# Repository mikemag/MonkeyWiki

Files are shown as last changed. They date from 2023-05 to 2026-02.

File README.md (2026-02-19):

# MonkeyWiki

This is the source for the content at https://www.happymonkeysnowboards.com/MonkeyWiki.

This was all converted from the Wiki version of MonkeyWiki in May, 2023. Hopefully I got everything right!

# Donate

You can help offset the server costs for running [MonkeyWiki](https://www.happymonkeysnowboards.com/MonkeyWiki) with a small donation. 



# Requirements

* hugo v0.154.2+extended or higher
* [Hugo Book Theme](https://github.com/alex-shpak/hugo-book) @ 81a841c92d62f2ed8d9134b0b18623b8b2471661

# License

Code is licensed under the MIT license except as otherwise noted.
See [LICENSE](https://github.com/mikemag/MonkeyWiki/blob/main/LICENSE) for details.

Documents and images are copyright by [Michael Magruder](https://github.com/mikemag) and licensed under a
[Creative Commons Attribution-ShareAlike 4.0 International License](http://creativecommons.org/licenses/by-sa/4.0/).

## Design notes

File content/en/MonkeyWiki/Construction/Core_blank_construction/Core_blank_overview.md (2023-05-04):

---
dateFromWiki: "2019-02-02T07:45:15Z"
title: "Core blank overview"
aliases:
- /MonkeyWiki/Core_blank_overview
- /MonkeyWiki/Core_blank_overview/en
weight: 1
---
Snowboard cores are typically composed of vertically laminated strips of wood about 2cm wide. The core is machined from a “core blank,” which is usually rectangular, longer, wider, and thicker than the final core.

Making a core blank is a fairly classic woodworking process, and you should approach it as such. If you’re new to woodworking I have collected a lot of [Woodworking Resources]({{< ref "MonkeyWiki/Resources/Woodworking_Resources.md" >}}) to help you get started. 

## Overview 
For snowboard cores, I build blanks that are about 13.5” wide, 0.400" thick, and about 6-7’ long. Each blank has 18 strips of poplar running lengthwise. The blank is held together with Polyurethane glue.

The process starts with poplar boards which are a bit over 7’ long, 2.5” wide, and approximately 3/4" thick. Nine of these boards are glued into a stack 7’ long, 2.5” wide, and 6.75” thick. The stack is sliced into 4 planks each 7’ long, 6.75” wide, and about 1/2" thick. Two slices are then joined together to make a blank 7’ long, 13.5” wide, and 0.400-0.500" thick. 

So, nine **boards** &rArr; one **stack** &rArr; four **slices** &rArr; two **blanks**. I will use the terms board, stack, slice, and blank to refer to the various stages of construction below.

I usually try to make about ten blanks at a time, so I start with at least 45 poplar boards. (I usually buy closer to 50 because sometimes what looks like a good board at the store doesn’t look so good in your shop!) I find that making many blanks at once is easier than making one at a time. Core blanks are very stable and can sit on the shelf for a very long time without warping or cracking.

## See Also 
- [Wood selection, drying, and prep]({{< ref "MonkeyWiki/Materials/Wood_selection__drying__and_prep.md" >}})
- [Building a stack]({{< ref "MonkeyWiki/Construction/Core_blank_construction/Building_a_stack.md" >}})
- [Slicing a stack]({{< ref "MonkeyWiki/Construction/Core_blank_construction/Slicing_a_stack.md" >}})
- [Joining the halves of a core blank]({{< ref "MonkeyWiki/Construction/Core_blank_construction/Joining_the_halves_of_a_core_blank.md" >}})

## To-do 
- Drawing of the progression from boards to blanks. Used to have one on the original HMS site… probably re-do it to make it look a bit less ghetto.
- Pics of each stage, just one per stage.

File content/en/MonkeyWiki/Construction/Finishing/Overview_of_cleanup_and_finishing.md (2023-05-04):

---
dateFromWiki: "2019-02-03T02:29:52Z"
title: "Overview of cleanup and finishing"
gallery: true
aliases:
- /MonkeyWiki/Overview_of_cleanup_and_finishing
- /MonkeyWiki/Overview_of_cleanup_and_finishing/en
weight: 1
---
{{< img src="images/Board_Trimmed.JPG" caption="_Snowboard with edges trimmed and cleaned up._" >}}After the board comes out of the press we still have a lot of cleanup work to be done before it really starts looking like a snowboard.

## Trimming the flash 
 
The first step is trim off the “flash”, which is the leftover material beyond the edge of the snowboard. This consists of extra fiberglass, cured epoxy, rubber, top sheet, nose/tail spacers, and sidewall material. I start by using a bandsaw to remove the flash from along the effective edge of the board. This is easily done by allowing the bandsaw blade to press against the metal snowboard edge. It is also possible to remove the flash from the nose and tail using the bandsaw, but I chose to cut these portions away using a jigsaw with an abrasive bit. It’s much easier (for me) to hold the board steady on a workbench and guide the jigsaw carefully around the tighter nose and tail radius than it is to swing the entire board around the bandsaw blade. 

@TODO: get the info on the blade I use.

{{< gallery  caption="Flash Cleanup" >}}
{{< gallery-item src="images/FlashCleanup1.JPG" caption="Remains of the nose and tail flash." >}}
{{< gallery-item src="images/FlashCleanup2.JPG" caption="Remains of the flash from along the edge of a snowboard." >}}
{{< /gallery >}}

## Cleaning the edges 
 
Now the laminate is starting to look more like a snowboard, but the edges are very rough. Both tools leave a rough edge, and in places there will still be a thin layer of excess material, usually PTEX sidewall or nose/tail spacer. A 4” angle grinder with a 60 grit flap sanding disc is used along the entire perimeter of the board. Excess material is carefully ground away, and the full edge is exposed. I then switch to a 120 grit flap sanding disc and cleanup the nose and tail portions of the board completely. This will be the final treatment these parts of the board receive. This is a pretty delicate process. You can do a lot of damage to the edge of the board with an angle grinder and a 60 or 120 grit disc in an amazingly short period of time!
 
It is critical that you not overheat the edges while grinding with the angle grinder. I constantly move to another area even before the portion I’m working on is done. I spray liberally with clean water as I do, and check the temperature of the edge with my hand. If you can’t hold your hand on the edge, then it’s too hot.

{{< gallery  caption="Edge cleanup" >}}
{{< gallery-item src="images/EdgeCleanup1.JPG" caption="The table where I cleanup the board. Snowboard vises are used to hold the board up on edge for grinding." >}}
{{< gallery-item src="images/EdgeCleanup2.JPG" caption="Laminate trimmer and angle grinder with various flap sanding discs." >}}
{{< /gallery >}}

## Base grind 
 
{{< img src="images/BaseGrinder.JPG" caption="_Base grinder_" >}}Next, the board gets its first base grind. I start with a coarse 80 grit belt to quickly remove the excess epoxy and a thin layer of base material, then switch to a 120 grit belt for the final grind. While the 80 grit belt is still in place, I cleanup the effective edge holding the board perpendicular to the base grinder. This ensures that the full length of the edge is smooth and even the length of the board.

## Beveling the sidewalls 
 
Next, the board is returned to the work bench where the sidewall bevel is applied. A laminate trimmer with a tilt base is used to run a flush trim router bit along the length of the effective edge. This gives the sidewall a perfect 10 degree bevel, and is the last bit of cleanup needed on the sidewalls. If you don’t have a laminate trimmer with a tilt base you can build a wedge out of wood and attach it to the base of your router to form the correct angle.
 
The key here is to move slowly and ensure that the base of the trimmer remains flat against the base of the board. Ease into and out of the cut at each end, and blend any sharp transition that might be left with a sanding block.

{{< gallery  caption="Sidewall cleanup" >}}
{{< gallery-item src="images/Trimmer1.jpg" caption="Laminate trimmer with a tilt base." >}}
{{< gallery-item src="images/Trimmer2.jpg" caption="Straight cutter with bearing on top." >}}
{{< gallery-item src="images/Trimmer3.jpg" caption="Example of how to apply the trimmer to cleaning up sidewalls. The edge should be completely exposed and smooth. The bearing rests on the edge, and the cutter starts about a half millimeter past the edge. The board is upside down and the trimmer rests on the base." >}}
{{< /gallery >}}

## Exposing the inserts 
 
Finally, the inserts are drilled out. I locate the inserts by using two small magnets that will stick to two 3/16” steel ball bearings that I placed in the guide inserts during preparation for layup. The guide inserts are centered along the length of the board, and 4cm from the first set of inserts. Using a guide I can quickly mark where the inserts are below the surface of the board, then drill them out in two steps. The first step is to use a 1/8” drill bit to open up the inserts, then a 45 degree counter sink to expose the full inserts and leave a nice bevel. The counter sink will self-center in the insert. Keep the drill perpendicular to the board to ensure an even, round hole. The threads are cleaned up with a M6 tap, and checked by running a binding screw down into each insert by hand. If the screw doesn’t feed easily all the way to the bottom, the tap is used again until it does.
 
Use a small pair of tweezers to remove bits of the mylar insert cap that get pushed down during drilling and counter sinking. Clear the inserts with compressed air before tapping and before running the screw down.
 
Go easy with the M6 tap. You don’t want to cross thread it and destroy the threads in an insert. You also don’t want to run it too far down and push out the base of the insert, which would leave a dimple on the bottom of the board. Most taps come with a point at the end. It’s best to grind this down to a flat bottom, as shown in the pictures below.

{{< gallery  caption="Insert cleanup" >}}
{{< gallery-item src="images/CleanupInserts1.JPG" caption="Insert finding guide, aligned with magnets." >}}
{{< gallery-item src="images/CleanupInserts2.JPG" caption="Insert finding guide, aligned with magnets." >}}
{{< gallery-item src="images/CleanupInserts3.JPG" caption="Insert finding guide, aligned with magnets." >}}
{{< gallery-item src="images/CleanupInserts4.JPG" caption="Inserts drilled with a small drill bit." >}}
{{< gallery-item src="images/CleanupInserts5.JPG" caption="Inserts exposed with the counter sink." >}}
{{< gallery-item src="images/CleanupInserts6.JPG" caption="Here you can see bits of epoxy and glass forced down into the inserts after drilling with the counter sink." >}}
{{< gallery-item src="images/CleanupInserts7.JPG" caption="Cleaning up the threads of the inserts with a M6 tap." >}}
{{< gallery-item src="images/CleanupInserts8.JPG" caption="Testing the insert threads with a binding screw." >}}
{{< /gallery >}}

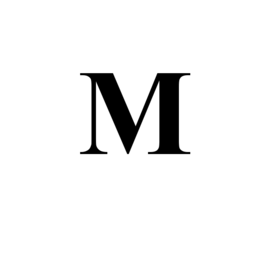
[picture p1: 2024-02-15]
static/mstile-150x150.png

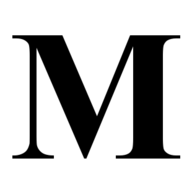
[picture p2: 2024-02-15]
static/android-chrome-192x192.png

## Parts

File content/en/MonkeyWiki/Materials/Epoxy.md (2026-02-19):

---
title: "Epoxy"
gallery: true
aliases:
  - /MonkeyWiki/Epoxy
  - /MonkeyWiki/Epoxy/en
---

{{< img src="images/Epoxy1.JPG" >}}
{{< img src="images/Epoxy2.JPG" >}}
I used an epoxy system specifically designed for ski and snowboard applications
by QCM Industrial, who used to be a local company. The epoxy is designed to be flexed and resist impact at
extremely low temperatures. The epoxy resin (EMV-0049) and hardener (ECA-032) are mixed by weight. It's measured out and
weighed to the gram, then mixed thoroughly. The boards are pressed with carefully controlled heating, on the top and
bottom of the board, to cure the epoxy properly so it will develop its full properties. The manufacturer recommends a
heated cure of 180F for this particular epoxy system.

### QCM no longer available

Note: this QCM epoxy is no longer available. They sold their formula to Forrest Paint who produced it for a few
years but they also stopped. I don't have a recommendation for different epoxy since I don't have any direct
experience with others for snowboard building. 

For posterity's sake, here are the data sheets on EMV-0043 and ECA-032. I don't have a copy of the EMV-0049 datasheet, 
but this is close enough. I switched to EMV-0043 at some point, I don't recall when.

- [EMV-0043 Data Sheet](/files/EMV-0043.pdf)
- [ECA-032 Data Sheet](/files/ECA-032.pdf)

## Quality Control

Whenever you get a new batch of epoxy you should label the cans and always use them in sets. Mix a 100g test sample,
cure it properly, and do a basic stress test on it (i.e., break it). Ensure it behaves as you expect, and as it has for
you in the past. One time I got a can of resin that was incorrect, and the 100g sample showed the problem immediately. I
took the cans and the sample back to the manufacturer, and they apologized and replace it right away.

If you’re selling your boards or skis, I highly recommend recording which batches of epoxy you use in each build. Save
the tests so you can refer back to them if someone reports a problem.

## Measurement

Every epoxy system is different: some are measured and mixed by **volume**, and some are measured by **weight**. It is
important you know which way you should measure for your epoxy. Mixing by volume with epoxy that needs to be mixed by
weight will result in either too much hardener (and it will kick too fast) or too little, in which case the epoxy will
not cure properly.

## Mixing

I use a “two-cup” mixing method. I use two cups which are individually large enough to hold the entire volume of mixed
epoxy. I measure out the hardener into Cup A and the resin into Cup B. I pour the hardener from Cup A to Cup B, and mix
thoroughly in Cup B. I then pour Cup B into Cup A, being careful to scrape the bottom and sides of Cup B to make sure I
get any un-mixed resin out. I then continue to mix in Cup A. This ensures that no resin is left on the bottom of Cup B.

A good trick you can use to help you learn if you’re mixing well or not is to add a very small amount of pigment to your
hardener before you start mixing. Pickup a small bottle of epoxy pigment and put just a smidge (dab the tip of a tongue
depressor in it) into the hardener and mix will. Now when you mix the hardener with the resin you will see easily any
unmixed resin. This small amount of pigment will not appreciably color your final mix of epoxy, and will be unnoticeable
in your final board.

## Safety

There are two safety aspects to be concerned about: fire, and long-term sensitivity.

### Fire

Epoxy cures via an [exothermic reaction](http://en.wikipedia.org/wiki/Exothermic_reaction). That means it generates heat
while it cures, and as it gets warmer it generates more heat. Given enough epoxy and heat this reaction can “run away”
and generate an amazing amount of heat, enough to ignite the epoxy or whatever it is near. Needless to say, that’s bad.
Even if it doesn’t ignite it can smolder and generate a toxic smoke that you should avoid.

'*Leftover epoxy should simply *never* be left in a cup when you are done with it.*' Pour it out onto a plastic picnic
plate or something equally disposable and let it cure slowly in a thin film. Never leave a cup with even an inch of
epoxy in the bottom sit to cure on its own, or toss such a cup in the trash, etc.

### Sensitivity

You should keep epoxy off your skin, and avoid inhaling epoxy dust as you process your board or skis after pressing.
Some people can develop a sensitivity to the chemicals in epoxy with repeated exposure over a long period of time. This
can cause skin rashes or breathing problems when exposed to a minimal amount of epoxy, and essentially leave you in the
position of not being able to work with it again.

Rubber gloves, long-sleeve work shirts, and simple dust masks are your friends here. Use them every time.

- [Health risks of epoxy at Wikipedia](http://en.wikipedia.org/wiki/Epoxy#Health_risks)
- [Epoxy School article on sensitization](http://www.epoxyschool.com/blog/?p=397)

## Interview with an epoxy chemist

[SkiBuilders](http://skibuilders.com) did a [Q&A with Roy Wheeldon](http://www.skibuilders.com/articles/epoxy.shtml)
back in 2007. He was the head chemist at QCM, Inc., the original makers of the epoxy that I and many others use for skis
and snowboards. It’s an excellent read and I highly recommend it. Roy was a nice guy and always helpful to small
builders like myself. I had the pleasure of talking with him about what I was doing many times. Sadly, Roy passed away a
few years ago.

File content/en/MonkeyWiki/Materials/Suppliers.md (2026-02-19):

---
title: "Suppliers"
aliases:
- /MonkeyWiki/Suppliers
- /MonkeyWiki/Suppliers/en
weight: 1
---

## Home Builders 
For home builders who are just making a few boards casually, I highly recommend starting with [Blank Slate Skis](http://www.blankslateskis.com/), which is run by Kelvin Wu of [Maiden Skis](https://maidenskis.com/). Kelvin is one of the original founders of the [SkiBuilders.com Forum](http://www.skibuilders.com/phpBB2/) and an all-around good guy. He supplies small builders with the same high quality materials he uses on his skis.

Next, take a look at [snowboardmaterials.com](https://snowboardmaterials.com/), which has been around longer than any other small supplier and has everything you need to get started. 

## Small Professional Builders 

For small professional builders, to get cost down you need to buy in quantity. Here are the sources I used at Happy Monkey throughout the years. Hopefully these sources remain available, as it is actually rare to find big businesses willing to sell in small quantities. I'll try to update this over time as I hear that things change, but I build about a board per year now so I don't buy supplies that often anymore. If you find a supplier that's out of date, or have a suggestion of one to add, please let me know!

This list focuses on North American suppliers, because that's where I am.

Be prepared to order in real quantity, and be prepared to be at the bottom of the priority list. Sourcing material in bulk, and ensuring you have it when you need it will be a test of your long-term logistical skills… leave lots of time to replenish.

- [CDW Edge](https://www.waelzholz.com/en/company/international/usa.html) - now owned by [Waelzholz](https://www.waelzholz-skikanten.de/en.html), but apparently still making and selling edges in Cleveland, OH. 
- [Crown Plastics](https://crownplastics.com/) - DuraSurf base material, nose & tail fill, PTEX sidewalls, clear top sheets. Crown is a large supplier, but has been solid when it comes to supplying smaller builders.
- [Composites One](https://www.compositesone.com/) - fibers, and where I got all of my Vectorply fiberglass. 
- [Fiberlay](http://www.fiberlay.com/) - small-quantity fibers, a good place to get bits of carbon and Kevlar.
- [Custom Components Group, Inc.](http://www.customcomponentsgroup.com) - all manner of inserts. This is where I got all of mine.
- [Miller Studio](http://www.millerstudio.net/) - printed top sheets. Vince Miller is awesome to work with. He did all of my printed top sheets before I switched to wood veneer. He'll help you figure out what you need and you'll end up with great graphics. Singles or bulk. He also sells bulk top sheet and base material.
- **UPDATE: Forrest has stopped making QCM epoxy.** 
  - [FORREST Technical Coatings](http://forrestpaint.com/) - this is who bought QCM's epoxy formulas when they stopped making epoxy. Call them up, tell them you're looking for the ski and snowboard specific epoxy QCM used to make and they'll know what you're talking about. I used to use QCM product numbers ECA-032 and EMV-049. Forrest still makes the ECA-032 as their [FORREST Medium Cure Hardner](http://forresttechblog.com/sportboard-builders-qcm/forrest-medium-cure-hardner/), and they have EMV-043, which I use now, as their [FORREST Epoxy Resin 218S000](http://forresttechblog.com/sportboard-builders-qcm/forrest-epoxy-resin-218s000/).
- [Michaels Enterprises, Inc.](https://www.michaelsenterprises.com) - heat blankets for your press. I got mine here, and they've held up for 15 years at this point.
- [McMaster-Carr](https://www.mcmaster.com/) - any part for any machine, tools, shop supplies, etc. I love this place. They have 3D models for all of their machine parts, which you can import directly into your favorite CAD system. Use this when designing new equipment.
- [Veneer Supplies](https://www.veneersupplies.com/) - great online supplier of wood veneer. Massive selection, excellent shipping. I've gotten a lot from here.
- CAMAX Tool Company, Inc. - inserts, famous for their magnetic capped inserts. I've never used them, but lots of people have. They don't seem to have a website, but they're in Ft. Morgan, Colorado, and you can google up a phone number.
- [Airtech](https://www.airtechonline.com/) - all things vacuum bagging, including tools.

Seattle-area suppliers:

- [Edensaw](http://www.edensaw.com/) - wood veneer mecca. You can go to their warehouse in Tacoma and look at the veneer before you buy it. They require you to take whole bundles, and they may not let you take a single bundle from the middle of a log. They often have broken bundles you can buy a few sheets from.
- [Compton Lumber](https://www.comptonlbr.com) - excellent source for core wood, like Poplar, Ash, etc. Good selection and prices. I've gotten all of my core wood from them for over a decade.
- [Alaskan Copper](http://www.alascop.com/) - great source of metal. I get my mold skins from them.
- [Eastside Saw & Sales](http://www.eastsidesaw.com/) - router bits, bandsaw blades, sharpening, etc.
- [Woodcraft Seattle](https://www.woodcraft.com/stores/seattle) - standard woodworking store. Rockler is good too, but you've gotta have your go-to woodworking store and this is mine.

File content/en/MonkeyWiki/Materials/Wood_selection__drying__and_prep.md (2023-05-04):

---
dateFromWiki: "2019-02-12T01:41:23Z"
title: "Wood selection, drying, and prep"
gallery: true
aliases:
- /MonkeyWiki/Wood_selection,_drying,_and_prep
- /MonkeyWiki/Wood_selection,_drying,_and_prep/en
---
{{< img src="images/Core_Wood.JPG" caption="_Poplar from Compton Lumber in Seattle._" >}}You can make a core blank out of pretty much any type of wood. The only wood I use in my blanks is poplar; I add a bit of ash along the edge of the core later when [Ash edge stringer and sidewalls]({{< ref "MonkeyWiki/Construction/Core_construction/Ash_edge_stringer_and_sidewalls.md" >}}). Many people use combinations of various types of wood throughout the core, in different patterns. Almost anything will work, so be creative.

{{< img src="images/Core_Wood_Clear.JPG" caption="_Clear poplar._" >}}No matter which type of wood you use, selecting quality boards is critical. You want clear boards with even grain, no knots, and preferably as straight as possible. Ideally all of the boards should be a bit longer than the final core blank length.

The best place to source your core wood is a dedicated lumber yard that sells rough cut wood. It is rarely cost-effective to get your wood at a big-box store like Home Depot or Lowes, even if they have the wood you want. In the Seattle area there are many excellent options. I always get my core wood from [Compton Lumber](http://www.comptonlbr.com/). They have an excellent selection of rough poplar as well as poplar already machined to the size I need. I also get my ash from them, always rough cut. You can spend the time at a place like Compton to pick through their stacks of wood and find just the boards you’re looking for. 

Other good choices in the Seattle area are [Crosscut Hardwoods](http://www.crosscuthardwoods.com/), and if you’re closer to the Olympic peninsula [Edensaw](http://edensaw.com/).

Purchasing wood from a real hardwood supplier is often confusing. There are a lot of odd terms that you may not initially be familiar with. [The Language of the Lumberyard](https://www.finewoodworking.com/2011/07/28/the-language-of-the-lumberyard) at Fine Woodworking is a good introduction to the topic, as is the video blog entry [A Lumbering Feeling](http://thewoodwhisperer.com/episode-4-a-lumbering-feeling/) from The Wood Whisperer.

{{< img src="images/Core_Wood_Blemish1.JPG" caption="_Knots at the ends can be okay._" >}}You want FAS (firsts and seconds), as clear as possible, and straight with minimal twisting or bowing. If you want it already prepared so you don’t need to do much work to the wood get S4S (surfaced on four sides). Note that if a board has a knot or other blemish near the end it may be alright. Often blanks come out much longer than they need to be and a knot near the end would not be included in the final core when cut.

## Preparing the boards 
We need poplar boards which are at least 7’ long, 2.5” wide, and about 0.75” thick, and we’ll need nine per stack. Happily, Compton Lumber sells poplar already machined perfectly to 2.5” wide and 0.75” thick in lengths ranging from 6’-8’. If I find a bunch of 6’ board I’ll tend to make some blanks for shorter boards… these blanks will tend to end up about 175-180cm long, which can yield cores of 173-178cm.

If you can’t find your wood already cut as you need then you can start from rough stock. This is the way I used to start before I got lucky with Compton. There is an excellent article from Fine Woodworking on turning rough cut lumber into useful boards here: @TODO. Following this process requires a table saw, a jointer, and a planer, all of which you need anyway for steps later in the process. It takes some extra time to do this, in particular some extra acclimation time for the wood (see below), but it’s a bit cheaper to start with rough wood that it is to buy it pre-machined, and you can customize the thickness of the strips in your core. 

## Acclimating the wood to your shop 
No matter how you get your boards you need to first let them adjust to the climate in your shop. Wood moves with moisture changes, and the moisture content of your shop if often quite different than the place you bought it from. Stack the wood on a flat bench with “stickers” in between; small pieces of wood used to separate the boards and let air flow around them. Place some heavier boards on the top of the stack to help ensure that the wood remains as flat as possible, and make sure that the stickers line up one on top of the other. Let the wood rest in your shop for at least a few days if you have narrow boards, and longer for thicker/wider boards. The wood will change shape slightly then stabilize. It’s better for it to change shape before you try to build something with it than during or afterwards. 

{{< gallery  caption="Drying core wood" >}}
{{< gallery-item src="images/Core_Wood_Drying1.JPG" caption="2.5\" x 0.75\" x 6-8' poplar stickered and drying before use as core wood." >}}
{{< gallery-item src="images/Core_Wood_Drying2.JPG" caption="2.5\" x 0.75\" x 6-8' poplar stickered and drying before use as core wood." >}}
{{< gallery-item src="images/Core_Wood_Drying3.JPG" caption="2.5\" x 0.75\" x 6-8' poplar stickered and drying before use as core wood." >}}
{{< /gallery >}}

## See Also 
- [Core blank overview]({{< ref "MonkeyWiki/Construction/Core_blank_construction/Core_blank_overview.md" >}})
- [Building a stack]({{< ref "MonkeyWiki/Construction/Core_blank_construction/Building_a_stack.md" >}})
- [Slicing a stack]({{< ref "MonkeyWiki/Construction/Core_blank_construction/Slicing_a_stack.md" >}})
- [Joining the halves of a core blank]({{< ref "MonkeyWiki/Construction/Core_blank_construction/Joining_the_halves_of_a_core_blank.md" >}})

## To-do 
- Article link on taking wood from rough to S4S.

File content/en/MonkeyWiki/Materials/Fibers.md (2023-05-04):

---
dateFromWiki: "2019-03-23T19:00:30Z"
title: "Fibers"
gallery: true
aliases:
- /MonkeyWiki/Fibers
- /MonkeyWiki/Fibers/en
---

## Glass 
{{< img src="images/Fibers1.JPG" >}}The primary reinforcement I use in my boards is 
[Vectorply](http://www.vectorply.com/) [E-TLX 2200](http://vectorply.com/wp-content/uploads/2015/06/E-TLX-22001.pdf), 
which is a stitched triaxial E-Glass. 54% of the fibers run in the longitudinal direction (0 degrees) while the other 
46% of the fibers are evenly divided between the 45 and -45 degree directions. The fibers are stitched together in three 
layers, rather than being woven like tradition fiberglass, which is what most of us are familiar with. 
[E-TLX-1900](http://vectorply.com/wp-content/uploads/2015/06/E-TLX-19001.pdf) is a nice, slightly lighter alternative 
which keeps the same volume of fibers in the +/-45 degree directions.

## Stitched vs. Woven Fabrics  
I greatly prefer non-woven fabrics for snowboard and ski applications. Weaving causes stress points everyplace a bundle 
of fibers crosses over or under another bundle. The constant flexing of a snowboard causes a rapid breakdown of the resin 
around these stress points, leaving the fibers unsupported and thus prone to breaking. Boards built with woven fabrics 
lose their stiffness far more quickly than we find acceptable. Stitched fabrics allow the fibers of each layer to lay 
flat on top of each other yielding a stronger laminate over time. Further, stitched fabrics trap less resin than woven, 
resulting in a lighter laminate.

Vectorply has a good page on the differences between woven and stitched fabrics for these kinds of applications. Here's a good summary from their page:

> The crimping of yarns, inherent in weaving, causes stress points in the laminate and a subsequent knockdown in strength 
> and stiffness. Pound for pound non-crimp reinforcements are 30% stronger than woven fabrics. Secondly, the coarse surface 
> created by the weaving of fibers translates into poor shear properties because of less fiber-to-fiber contact. Third, the 
> interstices created by the weave allow resin to pool amongst the rovings contributing to lower properties, adding unwanted weight and cost.

-- *Vectorply. (n.d.). Stitch-Bonded Reinforcements. Retrieved from http://vectorply.com/stitch-bonded-reinforcements/ on 2019/02/08.*

## Carbon and Kevlar  
{{< img src="images/Fibers9.JPG" >}}In addition to the fiberglass, I use Kevlar and carbon fiber in various places. 
Every board gets a very light weave of Kevlar backing the inserts. And, yes, having just explained why woven fabrics 
are bad in snowboards, this small application of such a light Kevlar weave is alright in this area as it receives so 
little flex. A patch of Kevlar which the inserts are pushed through provides stronger insert retention, and greatly 
reduces “binding suck”: that phenomena where the base underneath the bindings tends to suck in to the core when the 
bindings are tightened.
 
Unidirectional Kevlar or carbon is used on some boards to provide extra stiffness and pop depending on the application. 
An especially large board might be reinforced with Kevlar strips along the base to help provide stiffness while keeping 
the core thinner, and thus reducing weight. Kevlar or carbon may be used in just the nose or tail section, or spread 
between the bindings and the nose or tail in order to give more torsional rigidity. I use 1” wide unidirectional Kevlar 
and carbon fiber, and in some applications many very thin strips of carbon roving.

Note: Unused KEVLAR® should be stored away from UV light. It will degrade in UV light.

{{< gallery  caption="Various fibers and reinforcements" >}}
{{< gallery-item src="images/Fibers2.JPG" caption="Placement of 1” unidirectional Kevlar along the base of a 200cm custom board." >}}
{{< gallery-item src="images/Fibers3.JPG" caption="Light Kevlar weave to back the inserts. Slits are cut to allow the barrel of the inserts to pass through and still keep the Kevlar flat and even behind the inserts." >}}
{{< gallery-item src="images/Fibers4.JPG" caption="Close up of 1” unidirectional Kevlar." >}}
{{< gallery-item src="images/Fibers5.JPG" caption="Placement of 1” unidirectional Kevlar along the base of a 200cm custom board." >}}
{{< gallery-item src="images/Fibers6.JPG" caption="Unidirectional carbon fiber, 1” and 12”." >}}
{{< gallery-item src="images/Fibers7.JPG" caption="Detail of unidirectional carbon fibers." >}}
{{< gallery-item src="images/Fibers8.JPG" caption="Carbon fiber roving." >}}
{{< /gallery >}}

## Fibers I've Used 
- [Vectorply](http://www.vectorply.com/) [E-TLX 2200](http://vectorply.com/wp-content/uploads/2015/06/E-TLX-22001.pdf)
- [Vectorply](http://www.vectorply.com/) [E-TLX-1900](http://vectorply.com/wp-content/uploads/2015/06/E-TLX-19001.pdf)
- Kevlar, biax, woven, 1.70 oz./yd.² (58 g/m²) Warp 34 Kevlar 49 195 Denier x Fill 34 Kevlar 49 195 Denier, Plain Weave, 3.0 mils (.08 mm) Thickness.
- Kevlar, unidirectional, heat set binder, 0.010" x 1", 6.8 oz./yd.².
- Carbon Fiber, unidirectional, heat set binder, 0.008" x 1", 5.3 oz./yd.².
- Carbon Fiber, unidirectional, 0.007" x 2.25", [Hexcel HexForce GA045](https://www.hexcel.com/user_area/content_media/raw/DSF_ga045.pdf), 4.4 oz./yd.², 6k.
- Carbon Fiber, unidirectional, 0.010" x 12", Hexcel GA060, 6.7 oz./yd.² (227 g/m²), Warp 7 12K Carbon x Fill 4 Proprietary Heatset, Plain Weave, 10.1 mils (.26 mm) Thickness.  
- Carbon Fiber, raw tow, [roll from EBay long ago](https://www.ebay.com/itm/AMOCO-CYTEC-THORNEL-P-100-2K-HIGH-STIFFNESS-CARBON-GRAPHITE-FIBER-TOW-THREAD/263531049599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), Aomco Performance Products, Inc., P100-2K, grade 304-NT, 1.02lbs, 4800ft, 0.003-0.004" x ~3mm. 110 Msi, 348 ksi, 10 um filament diameter, 2880 denier / 3200 dtex (0.32 g/m). 

## Safety  

Glass, carbon, and Kevlar fibers are very small and easily penetrate your skin. They also float in the air and are easily inhaled, 
where they settle in your lungs. Wear gloves when handling the fibers. Wear a very high quality dust mask and goggles when cutting 
any of these materials, either raw or in a laminate. This is especially important when trimming the flash from a ski or snowboard, 
and when sanding the sides of the boards, as this generates a great deal of fiber-rich dust.

## Terms 
- [Tow](https://en.wikipedia.org/wiki/Tow) - the raw fiber thread used to weave fabrics, i.e., an untwisted bundle of continuous filaments. A 2K tow is 2000 threads.   
- [Denier](https://en.wikipedia.org/wiki/Units_of_textile_measurement#Denier) - fiber thickness of individual threads.

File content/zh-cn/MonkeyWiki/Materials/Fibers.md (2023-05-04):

---
dateFromWiki: "2020-04-28T09:25:31Z"
title: "纤维织物"
gallery: true
aliases:
- /MonkeyWiki/Fibers/zh-cn
translatedDate: "2020-04-28T09:25:31Z"
translator: "X z"
translatorPage: "/zh-cn/MonkeyWiki/X_z"
---

==玻璃纤维==

{{< img src="images/Fibers1.JPG" >}}我在我的板上使用的主要强化是[Vectorply](http://www.vectorply.com/) [E-TLX 2200](http://vectorply.com/wp-content/uploads/2015/06/E-TLX-22001.pdf)，这是一种缝合的三轴E-Glass。54％的纤维沿纵向（0度）延伸，而另外46％的纤维均在45度和-45度之间均匀分布。纤维被缝合成三层，而不是像传统的玻璃纤维一样编织，这是我们大多数人都熟悉的。 [E-TLX-1900](http://vectorply.com/wp-content/uploads/2015/06/E-TLX-19001.pdf)是一个不错的，稍微轻一点的替代品，它可以保持相同体积的纤维+/-45度方向。

## 缝合与织物面料

我非常喜欢用于滑雪板应用的无纺布。编织会导致每束纤维在另一束上方或下方穿过的应力点。滑雪板的不断弯曲导致树脂在这些应力点周围快速破裂，使得纤维不受支撑并因此易于破裂。使用机织织物制造的板材比我们认为可接受的更快地失去其刚度。缝合的织物允许每层的纤维平放在彼此之上，随着时间的推移产生更强的层压。此外，缝合的织物比编织物捕获更少的树脂，导致更轻的层压物。

Vectorply对于这些应用的织造和缝合织物之间的差异有一个很好的页面。这是他们页面的一个很好的总结：

> 编织中固有的纱线卷曲会在层压板中产生应力点，并随后导致强度和刚度下降。英镑非卷曲增强材料的强度比机织织物强30％。其次，由于纤维与纤维的接触较少，由纤维编织产生的粗糙表面转化为差的剪切性能。 第三，由编织产生的间隙允许树脂在粗纱中聚集，从而导致较低的性能，增加了不必要的重量和成本。

-- *Vectorply. (n.d.). Stitch-Bonded Reinforcements. Retrieved from http://vectorply.com/stitch-bonded-reinforcements/ on 2019/02/08.*

## 碳纤维和凯夫拉纤维
{{< img src="images/Fibers9.JPG" >}}除了玻璃纤维，我还在各个地方使用凯夫拉纤维和碳纤维。每块板都有一层非常轻的凯夫拉编织衬垫。并且，是的，刚刚解释了为什么机织织物在滑雪板上不好，这种轻型凯夫拉织物的这种小型应用在这个领域是正常的，因为它接受的弯曲很小。插入插入物的凯夫拉贴片提供了更强的插入物保持力，并且大大减少了“结合吸收”：当固定器被收紧时，固定器下面的基部倾向于吸入板芯的现象。

某些板上使用单轴凯夫拉或碳纤维，根据应用提供额外的刚度和弹性。特别大的板可以用基部的凯夫拉条加固，以帮助提供刚度，同时保持芯更薄，从而减轻重量。凯夫拉或碳纤维可以仅用于板头或板尾，或者在绑带和鼻子或尾部之间展开，以提供更大的扭转刚度。我使用1英寸宽的单轴凯夫拉和碳纤维，在某些应用中使用许多非常薄的碳纤维条。

注意：未使用的KEVLAR®应远离紫外线。它会在紫外线下降解。

{{< gallery  caption="各种纤维和增强材料" >}}
{{< gallery-item src="images/Fibers2.JPG" caption="Placement of 1” unidirectional Kevlar along the base of a 200cm custom board." >}}
{{< gallery-item src="images/Fibers3.JPG" caption="Light Kevlar weave to back the inserts. Slits are cut to allow the barrel of the inserts to pass through and still keep the Kevlar flat and even behind the inserts." >}}
{{< gallery-item src="images/Fibers4.JPG" caption="Close up of 1” unidirectional Kevlar." >}}
{{< gallery-item src="images/Fibers5.JPG" caption="Placement of 1” unidirectional Kevlar along the base of a 200cm custom board." >}}
{{< gallery-item src="images/Fibers6.JPG" caption="Unidirectional carbon fiber, 1” and 12”." >}}
{{< gallery-item src="images/Fibers7.JPG" caption="Detail of unidirectional carbon fibers." >}}
{{< gallery-item src="images/Fibers8.JPG" caption="Carbon fiber roving." >}}
{{< /gallery >}}

## 我用过的纤维

- [Vectorply](http://www.vectorply.com/) [E-TLX 2200](http://vectorply.com/wp-content/uploads/2015/06/E-TLX-22001.pdf)
- [Vectorply](http://www.vectorply.com/) [E-TLX-1900](http://vectorply.com/wp-content/uploads/2015/06/E-TLX-19001.pdf)
- Kevlar, biax, woven, 1.70 oz./yd.² (58 g/m²) Warp 34 Kevlar 49 195 Denier x Fill 34 Kevlar 49 195 Denier, Plain Weave, 3.0 mils (.08 mm) Thickness.
- Kevlar, unidirectional, heat set binder, 0.010" x 1", 6.8 oz./yd.².
- Carbon Fiber, unidirectional, heat set binder, 0.008" x 1", 5.3 oz./yd.².
- Carbon Fiber, unidirectional, 0.007" x 2.25", [Hexcel HexForce GA045](https://www.hexcel.com/user_area/content_media/raw/DSF_ga045.pdf), 4.4 oz./yd.², 6k.
- Carbon Fiber, unidirectional, 0.010" x 12", Hexcel GA060, 6.7 oz./yd.² (227 g/m²), Warp 7 12K Carbon x Fill 4 Proprietary Heatset, Plain Weave, 10.1 mils (.26 mm) Thickness.  
- Carbon Fiber, raw tow, [roll from EBay long ago](https://www.ebay.com/itm/AMOCO-CYTEC-THORNEL-P-100-2K-HIGH-STIFFNESS-CARBON-GRAPHITE-FIBER-TOW-THREAD/263531049599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), Aomco Performance Products, Inc., P100-2K, grade 304-NT, 1.02lbs, 4800ft, 0.003-0.004" x ~3mm. 110 Msi, 348 ksi, 10 um filament diameter, 2880 denier / 3200 dtex (0.32 g/m). 

## 安全 

玻璃纤维，碳纤维和凯夫拉纤维非常小，很容易穿透你的皮肤。它们也漂浮在空气中，很容易吸入，在肺部沉淀。处理纤维时戴上手套。在切割任何这些材料时，无论是原始材料还是层压材料，都要佩戴高质量的防尘面罩和护目镜。当从滑雪板上修剪边角料以及在板的侧面打磨时，这尤其重要，因为这会产生大量富含纤维的灰尘。

## 条款

- [Tow](https://en.wikipedia.org/wiki/Tow)  - 用于编织织物的原纤维线，即无捻的连续长丝束。 2K丝束是2000个丝线。
- [Denier](https://en.wikipedia.org/wiki/Units_of_textile_measurement#Denier)  - 单个线程的纤维厚度。

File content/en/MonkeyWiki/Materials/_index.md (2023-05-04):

---
title: "Materials"
aliases:
- /MonkeyWiki/Materials_Overview
- /MonkeyWiki/Materials_Overview/en
weight: 3
bookCollapseSection: true
---
The following articles cover the materials that go into a snowboard. Most of these materials are fairly 
specialized: a particular kind of fiberglass, epoxy, base materials, etc. and while you can find substitutes 
for them, it’s not ideal. Others though, like the particular kind of core wood, can really be whatever you wish.

- [Suppliers]({{< ref "MonkeyWiki/Materials/Suppliers.md" >}})
- [Fibers]({{< ref "MonkeyWiki/Materials/Fibers.md" >}})
- [Epoxy]({{< ref "MonkeyWiki/Materials/Epoxy.md" >}})
- [Wood selection, drying, and prep]({{< ref "MonkeyWiki/Materials/Wood_selection__drying__and_prep.md" >}})

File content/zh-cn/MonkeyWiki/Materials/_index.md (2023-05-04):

---
title: "材料概述"
aliases:
- /MonkeyWiki/Materials_Overview/zh-cn
translatedDate: "2020-04-28T09:23:33Z"
translator: "X z"
translatorPage: "/zh-cn/MonkeyWiki/X_z"
weight: 3
bookCollapseSection: true
---
以下文章介绍了进入滑雪板的材料。大多数这些材料都是相当专业的：特殊种类的玻璃纤维，环氧树脂，基材等。虽然你可以找到他们的替代品，但这并不理想。但是，其他（例如特定种类的芯木）确实可以满足您的任何需求。

- [供应商]({{< ref "MonkeyWiki/Materials/Suppliers.md" >}})
- [纤维织物]({{< ref "MonkeyWiki/Materials/Fibers.md" >}})
- [环氧树脂]({{< ref "MonkeyWiki/Materials/Epoxy.md" >}})
- [木材选择，干燥和准备]({{< ref "MonkeyWiki/Materials/Wood_selection__drying__and_prep.md" >}})

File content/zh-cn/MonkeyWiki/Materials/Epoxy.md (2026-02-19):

---
title: "环氧树脂"
gallery: true
aliases:
- /MonkeyWiki/Epoxy/zh-cn
translatedDate: "2019-04-04T08:21:21Z"
translator: "X z"
translatorPage: "/zh-cn/MonkeyWiki/X_z"
---
{{< img src="images/Epoxy1.JPG" >}}
{{< img src="images/Epoxy2.JPG" >}}
我使用专为滑雪板应用设计的环氧系统，由当地公司QCM Industrial设计。环氧树脂设计为在极低温度下弯曲并抵抗冲击。测量环氧树脂（EMV-0049）和固化剂（ECA-032）并称重至克，然后充分搅拌。在板的顶部和底部通过小心控制的加热压制板，以适当地固化环氧树脂，从而发挥其全部特性。制造商建议对这种特殊的环氧树脂系统进行180°F(82°C)的加热固化。  

### QCM no longer available

Note: this QCM epoxy is no longer available. They sold their formula to Forrest Paint who produced it for a few
years but they also stopped. I don't have a recommendation for different epoxy since I don't have any direct
experience with others for snowboard building. 

For posterity's sake, here are the data sheets on EMV-0043 and ECA-032. I don't have a copy of the EMV-0049 datasheet, 
but this is close enough. I switched to EMV-0043 at some point, I don't recall when.

- [EMV-0043 Data Sheet](/files/EMV-0043.pdf)
- [ECA-032 Data Sheet](/files/ECA-032.pdf)

## 质量控制

每当你获得一批新的环氧树脂时，你应该标记罐头并始终成套使用。混合100g测试样品，适当地固化，并对其进行基本的压力测试（即打破它）。确保它的行为与你期望的一样，并且与过去一样。有一次我得到一罐不正确的树脂，100克样品立即显示出问题。我把罐头和样品带回制造商，他们道歉并立即更换。 

如果你正在销售滑雪板，我强烈建议你记录每个建造过程中使用的批量环氧树脂。保存测试，以便在有人报告问题时你可以参考它们。 

## 测量

每个环氧系统都是不同的：有些是用**体积**测量和混合的，有些是用**重量**测量的。重要的是你知道应该用哪种方法测量环氧树脂。需要按重量混合的环氧树脂按体积混合将导致过多的固化剂（并且它将固化得太快）或太少，在这种情况下环氧树脂将不能正确固化。 

## 混合

我使用“两杯”混合法。我使用两个杯子，它们各自足够大，可容纳整个体积的混合环氧树脂。我将固化剂测量后倒杯子A中，将树脂测量倒杯子B中。我将固化剂从杯子A倒入杯子B，并在杯子B中充分混合。然后将杯子B倒入杯子A中，小心刮去底部和侧面 杯B确保我得到任何未混合的树脂。然后我继续在杯子A中混合。这确保了杯子B底部没有树脂。

一个好的技巧，你可以用来帮助你了解你是否混合好是在开始混合之前向你的固化剂添加非常少量的颜料。取出一小瓶环氧树脂颜料，然后将一小块（压在其中的压舌板尖端）放入固化剂中并搅拌均匀。现在，当你将固化剂与树脂混合时，你将很容易看到任何未混合的树脂。这种少量颜料不会对最终的环氧树脂混合物产生明显的颜色，并且在最终的板材中不会引起注意。 

## 安全

有两个安全方面需要关注：火灾和长期敏感性。

### 火

环氧树脂通过[放热反应](http://en.wikipedia.org/wiki/Exothermic_reaction)治愈。这意味着它在固化时会产生热量，而当它变暖时会产生更多的热量。给予足够的环氧树脂和热量，这种反应可以“逃逸”并产生惊人的热量，足以点燃环氧树脂或其附近的任何东西。不用说，这很糟糕。即使它没有点燃它也可以闷烧并产生你应该避免的有毒烟雾。

当你完成它时，剩下的环氧树脂就应该“永远不会”留在杯子里。'''把它倒在塑料野餐盘上或者同样的一次性用品上，让它在薄膜中慢慢固化。永远不要在底部放置一个带有一英寸环氧树脂的杯子，以便自己固化，或者将这样的杯子扔进垃圾桶等。 

### 敏感度

你应该保持环氧树脂不被皮肤污染，并在层压后处理你的滑雪板时避免吸入环氧树脂灰尘。有些人可以长时间反复接触，对环氧树脂中的化学物质产生敏感性。当暴露于极少量的环氧树脂时，这可能导致皮疹或呼吸问题，并且基本上使你处于无法再次使用它的位置。 

橡胶手套，长袖工作衬衫和简单的防尘口罩是你的朋友。每次都使用它们。  

- [维基百科环氧树脂的健康风险](http://en.wikipedia.org/wiki/Epoxy#Health_risks) 
- [环氧学校关于致敏的文章](http://www.epoxyschool.com/blog/?p=397)

## 采访环氧化学家

[SkiBuilders](http://skibuilders.com)在2007年做了[与Roy Wheeldon的问答](http://www.skibuilders.com/articles/epoxy.shtml)。他是QCM,Inc. 的首席化学家，我和其他许多人用于滑雪板的原始环氧树脂制造商。这是一个很好的阅读，我强烈推荐它。罗伊是一个很好的人，总是对像我这样的小型制造商有所帮助。我很高兴和他谈论我多次做的事情。可悲的是，几年前Roy去世了。

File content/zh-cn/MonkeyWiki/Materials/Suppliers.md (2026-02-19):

---
title: "供应商"
aliases:
- /MonkeyWiki/Suppliers/zh-cn
translatedDate: "2019-04-17T09:24:32Z"
translator: "X z"
translatorPage: "/zh-cn/MonkeyWiki/X_z"
weight: 1
---

## 家庭作坊

对于只是偶尔制作几块滑雪板的家庭作坊，我强烈建议从[Blank Slate Skis](http://www.blankslateskis.com/)开始，这是由[Maiden](https://maidenskis.com/)的Kelvin Wu运营滑雪板材料商店。Kelvin也是[SkiBuilders.com论坛](http://www.skibuilders.com/phpBB2/)的原始创始人之一，也是一位全能的好人。他为小型制造商提供他在滑雪板上使用的高质量材料。

接下来，看看[snowboardmaterials.com](https://snowboardmaterials.com/)，它比任何其他小型供应商都要长，并且拥有入门所需的一切。 

## 小型专业制造商

对于小型专业制造商而言，要降低成本，你需要大量购买。以下是我在Happy Monkey多年来使用的资源。希望这些资源仍然可用，因为很难找到愿意少量出售的大企业。我会尝试随着时间的推移更新这一点，因为我听到事情发生了变化，但我现在每年都在制作一块滑雪板，所以我不再经常购买使用的耗材了。如果你发现供应商已过期，或者建议添加，请告知我们！

这份清单侧重于北美供应商，因为我就在这里。

准备好实际订购，并准备好在优先列表的底部。批量采购材料，并确保你在需要时拥有它将是对你的长期物流技能的考验......留出大量时间补充。

*[CDW Edge](https://www.waelzholz.com/en/company/international/usa.html) - 现在属于 [Waelzholz](https://www.waelzholz-skikanten.de/en.html), 但显然仍在俄亥俄州的克里夫兰市制造和销售边刃。 
- [Crown Plastics](https://crownplastics.com/) - DuraSurf板底材料, 板头&板尾垫片, PTEX边墙, 干净的顶片. Crown是一家大型供应商，但在供应小型制造商方面一直很稳固。
- [Composites One](https://www.compositesone.com/) - 纤维，我得到了所有的Vectorply玻璃纤维。
- [Fiberlay](http://www.fiberlay.com/) - 少量纤维，是获取碳纤维和凯夫拉纤维的好地方。
- [Custom Components Group, Inc.](http://www.customcomponentsgroup.com) - 各种嵌件。 这是我得到的全部。
- [Miller Studio](http://www.millerstudio.net/) - 印刷的顶片。Vince Miller很棒。在我换成木饰面之前，他做了我所有的印花顶片。他会帮助你弄清楚你需要什么，你最终会得到很棒的图形。单身或散装。他还销售散装顶片和板底。
- **UPDATE: Forrest has stopped making QCM epoxy.** 
  - [FORREST Technical Coatings](http://forrestpaint.com/) - 这是在他们停止生产环氧树脂时购买了QCM的环氧配方。打电话给他们，告诉他们你正在寻找滑雪板专用环氧树脂QCM，他们会知道你在说什么。 我以前使用QCM产品编号ECA-032和EMV-049。Forrest 仍然将ECA-032作为他们的[FORREST Medium Cure Hardner](http://forresttechblog.com/sportboard-builders-qcm/forrest-medium-cure-hardner/), 他们现在使用EMV-043作为他们的[FORREST Epoxy Resin 218S000](http://forresttechblog.com/sportboard-builders-qcm/forrest-epoxy-resin-218s000/).
- [Michaels Enterprises, Inc.](https://www.michaelsenterprises.com) - 为你的压力机加热毯子。我在这里得到了我的，他们在这一点上已经坚持了15年。
- [McMaster-Carr](https://www.mcmaster.com/) - 任何机器，工具，商店用品等的任何部分。我喜欢这个地方。他们拥有所有机器零件的3D模型，在设计新设备时使用此功能你可以直接导入到你喜欢的CAD软件中。
- [Veneer Supplies](https://www.veneersupplies.com/) - 很好的木皮在线供应商。大量选择，出色的运输。我从这里得到了很多。
- CAMAX Tool Company, Inc. - 嵌件，以其磁性加盖嵌件而闻名。我从来没有使用它们，但很多人都有。他们似乎没有网站，但他们在科罗拉多州摩根堡，你可以谷歌一个电话号码。
- [Airtech](https://www.airtechonline.com/) - 真空包装所有东西，包括工具。

西雅图地区供应商：

- [Edensaw](http://www.edensaw.com/) - 木饰面麦加。你可以前往Tacoma的仓库，在购买前查看木皮。它们要求你获取整个捆绑包，并且它们可能不允许你从日志中间取出一个捆绑包。他们经常打破捆绑，你可以买几张。

- [Compton Lumber](https://www.comptonlbr.com) - 板芯木材的优良来源，如杨树，白蜡木等。良好的选择和价格。十多年来，我从他们那里得到了我所有的板芯木材。

- [Alaskan Copper](http://www.alascop.com/) - 很好的金属来源。我从他们那里得到了我的模具皮。
- [Eastside Saw & Sales](http://www.eastsidesaw.com/) - 雕刻机刀具，带锯刀片，磨刀石等
- [Woodcraft Seattle](https://www.woodcraft.com/stores/seattle) - 标准木工商店。Rockler也很好，但是你必须拥有自己的木工店，这就是我的。

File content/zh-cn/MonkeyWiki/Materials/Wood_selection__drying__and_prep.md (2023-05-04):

---
dateFromWiki: "2020-04-28T09:29:58Z"
title: "木材选择，干燥和准备"
gallery: true
aliases:
- /MonkeyWiki/Wood_selection,_drying,_and_prep/zh-cn
translatedDate: "2020-04-28T09:29:58Z"
translator: "X z"
translatorPage: "/zh-cn/MonkeyWiki/X_z"
---
{{< img src="images/Core_Wood.JPG" caption="_来自西雅图康普顿的杨木材_" >}}你可以用几乎任何类型的木材制作空白板。我在空白板使用的唯一木材是杨木。在[白蜡木桁条和边墙]({{< ref "MonkeyWiki/Construction/Core_construction/Ash_edge_stringer_and_sidewalls.md" >}})这篇文章中，我会在板芯边缘添加一点白蜡木条。许多人在整个板芯中以不同的方式使用各种类型的木材组合。几乎任何事都可行，所以要有创意。

{{< img src="images/Core_Wood_Clear.JPG" caption="_干净的杨木_" >}}无论你使用哪种木材，选择优质木材都至关重要。你需要具有均匀纹理，无结的干净的木材，并且最好尽可能的直。理想情况下，所有的木材都要比最终的空白板长度稍长一点。

采购板芯木材的最佳地点是一个专门出售粗切木的木材场。在Home Depot或Lowes这样的大型商店 即使他们拥有你想要的木材，购买木材也很少有成本效益。在西雅图地区有很多很棒的选择。我总是从 [Compton Lumber](http://www.comptonlbr.com/)得到我的板芯木材。他们有很好的粗糙杨木和杨木的选择，并且已经加工到我需要的尺寸。我也从他们那里得到了白蜡木条，总是粗切的。你可以花时间在像康普顿这样的地方挑选自己的木材，找到你正在寻找的木板。 

西雅图地区的其他好选择是[Crosscut Hardwoods](http://www.crosscuthardwoods.com/),如果你离奥林匹克半岛更近还可以去[Edensaw](http://edensaw.com/)看看.

从真正的硬木供应商那里购买木材往往令人困惑。你可能最初并不熟悉许多奇怪的术语。
在Fine Woodworking[伐木场术语](https://www.finewoodworking.com/2011/07/28/the-language-of-the-lumberyard)是一个很好的介绍主题,来自The Wood Whisperer视频博客条目也是如此[A Lumbering Feeling](http://thewoodwhisperer.com/episode-4-a-lumbering-feeling/)

{{< img src="images/Core_Wood_Blemish1.JPG" caption="_结束处有木结也行_" >}}你想要一等品及二等品(硬木木材的最高等级)，尽可能干净，并且要直，最小的扭曲或弯曲。如果你想要它已经准备好所以你不需要做很多工作就可以得到S4S（四面浮出水面）。请注意，如果一块板在末端附近有结或其他瑕疵，它可能没问题。通常坯料的出现时间比它们需要的长得多，并且在切割时最终的板芯不会包括接近末端的木结。

## 准备木板

我们需要至少7英尺(约2.13m)长，2.5英寸(6.35cm)宽，约0.75英寸(约1.9cm)厚的杨木板，每个芯坯需要9块。令人高兴的是，Compton Lumber销售的杨木板已经完美加工成上述的尺寸，长度从6英尺到8英尺不等。如果我找到一堆6英尺木板，我会倾向于使用较短的板制作一些空白板......这些空白板将倾向于最终长约175-180厘米，这可以生产173-178厘米的板芯。

如果你无法找到已经切割过的木材，那么你可以从粗糙的原料开始。这是我在康普顿幸运之前开始的方式。Fine Woodworking的一篇优秀文章将粗切木材变成了有用的木板：@TODO。在此过程之后需要一个台锯，一个平刨和一个压刨，所有这些都是你在此过程中的后续步骤所需要的。这需要一些额外的时间来完成，特别是木材的一些额外的适应时间（见下文），但从粗糙的木材开始，它是预先加工的购买它，并且你可以自定义板芯中的木条厚度。 

## 使木材适应你的工作室

无论你如何获得木板，你都需要先让它们适应你工作室的气候。木材会随着水分的变化而变化，而你工作室的水分含量通常与你购买它的地方大不相同。将木板堆放在平板凳上，中间夹着“木条”; 用来分隔木板并让空气在它们周围流动的小块木头。在木板顶部放置一些较重的板，以确保木板尽可能保持平整，并确保木条一个在另一个上面。如果你有窄板，让木板在你的工作室“休息”几天，对于更厚/更宽的板，让其“休息”更长时间。木板会稍微改变形状然后稳定下来。在尝试使用它制作东西之前或之后更改形状会更好。 

{{< gallery  caption="干燥板芯木材" >}}
{{< gallery-item src="images/Core_Wood_Drying1.JPG" caption="2.5\" x 0.75\" x 6-8' poplar stickered and drying before use as core wood." >}}
{{< gallery-item src="images/Core_Wood_Drying2.JPG" caption="2.5\" x 0.75\" x 6-8' poplar stickered and drying before use as core wood." >}}
{{< gallery-item src="images/Core_Wood_Drying3.JPG" caption="2.5\" x 0.75\" x 6-8' poplar stickered and drying before use as core wood." >}}
{{< /gallery >}}

## 参阅

- [芯坯概述]({{< ref "MonkeyWiki/Construction/Core_blank_construction/Core_blank_overview.md" >}})
- [制作芯坯]({{< ref "MonkeyWiki/Construction/Core_blank_construction/Building_a_stack.md" >}})
- [切割芯坯]({{< ref "MonkeyWiki/Construction/Core_blank_construction/Slicing_a_stack.md" >}})
- [拼接另外一半空白板芯]({{< ref "MonkeyWiki/Construction/Core_blank_construction/Joining_the_halves_of_a_core_blank.md" >}})

## 待办事项

*关于从粗糙到S4S采伐木材的文章链接。

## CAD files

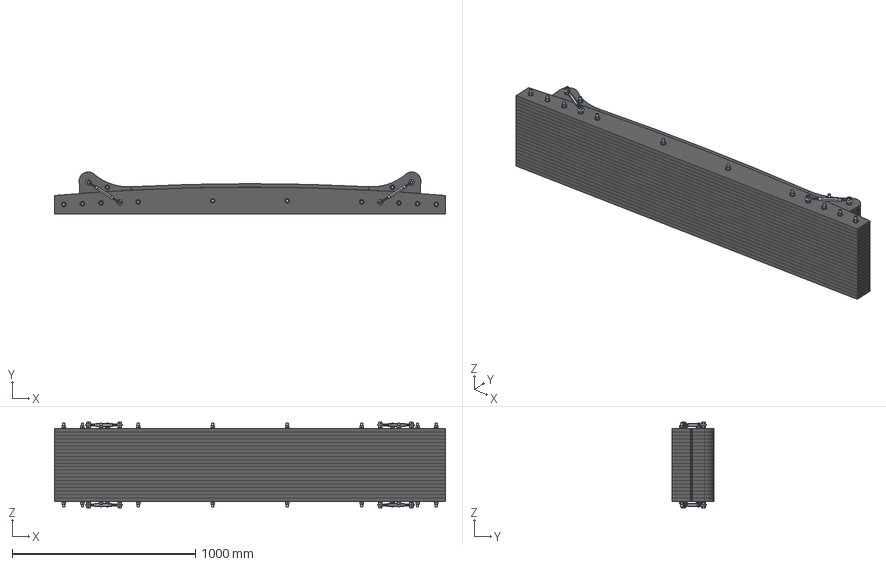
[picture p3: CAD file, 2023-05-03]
static/files/Snowboard_Mold_Basic_Public_v18.step
2133.6 x 230.0 x 467.4 mm
Camber Block Original Public x 21
93960A180 x 32
90490A033 x 42
Center Spacer
Center x 4

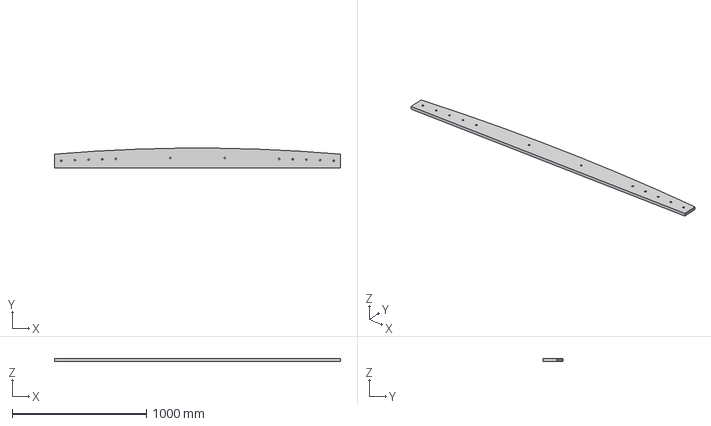
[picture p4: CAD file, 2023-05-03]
static/files/Camber_Block_Original_Public_v8.step
2133.6 x 146.3 x 19.0 mm

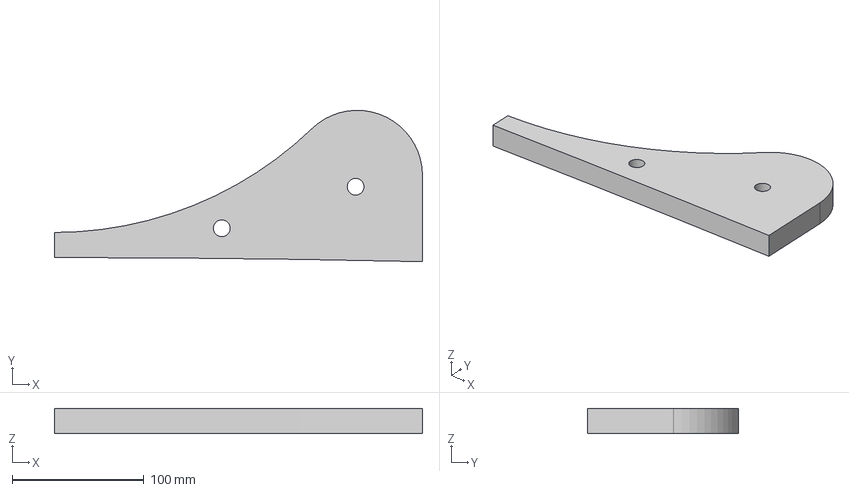
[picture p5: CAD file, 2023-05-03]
static/files/End_Block_Original_1_Public_v4.step
279.4 x 114.9 x 19.1 mm

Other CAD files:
static/files/Camber_Block_Original_Public_v8.f3d
static/files/End_Block_Original_1_Public_v4.f3d
static/files/Snowboard_Mold_Basic_Public_v18.f3z

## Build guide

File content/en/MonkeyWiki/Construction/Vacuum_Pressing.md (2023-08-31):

---
title: "Vacuum Pressing"
gallery: true
aliases:
  - /MonkeyWiki/Vacuum_Pressing
  - /MonkeyWiki/Vacuum_Pressing/en
---

{{< img src="images/Vacuum_boards.JPG" width=300px
caption="Boards built vacuum bagging, circa 2003." >}}

Vacuum pressing is a very reasonable way to press snowboards and skis. It's more
affordable, requires much less space, and is often a more flexible setup,
allowing you to build different shapes and sizes of boards easily.

I started by vacuum pressing, and did so for the first two years of board
building. All the pics here are from early 2003-ish.

## Resources and Links

There's a lot about vacuum bagging online. Look for info about composites, or
woodworking. Both are applicable.

* [Vacuum Bagging Equipment and Techniques for Room-Temp Applications](https://www.fibreglast.com/product/vacuum-bagging-equipment-and-techniques-for-room-temp-applications),
  an excellent overview by Fiber Glast.
* Supplies
  from [Fiber Glast](https://www.fibreglast.com), [Fiberglass Supply](https://fiberglasssupply.com/vacuum-bagging-supplies/),
  etc.
* [Joe Woodworker](https://www.joewoodworker.com/veneering/welcome.htm)
* [Vacu Press](https://www.vacupress.com/)
* Lots
  of [posts on vacuum bagging](http://www.skibuilders.com/phpBB2/search.php?keywords=vacuum+bagging)
  at SkiBuilders.com

## Molds

One of the best things about vacuum bagging is the molds. With a pneumatic
press, you have to have a completely solid and very strong mold to withstand the
pressure applied to it.
For bagging, the mold only needs to hold its shape against the stiffness of the
board's core.

I built my molds out of 5 ribs of MDF, with interchangeable nose and tail
sections. A single piece of aluminum is pre-bent and screwed to the top to form
the layup surface.

The skin is attached via screws, with
small [metal threaded inserts](https://www.mcmaster.com/90016A009/) placed
carefully into the outer two ribs. I recommend 3/4" MDF for the outer ribs and
careful drilling to ensure you don't split the MDF when you add the inserts.

{{< gallery caption="Vacuum Mold" >}}
{{< gallery-item src="images/Vacuum_mold_1.jpg" caption="" >}}
{{< gallery-item src="images/Vacuum_mold_2.jpg" caption="" >}}
{{< gallery-item src="images/Vacuum_mold_3.jpg" caption="" >}}
{{< gallery-item src="images/Vacuum_mold_4.jpg" caption="" >}}
{{< gallery-item src="images/Vacuum_mold_5.jpg" caption="" >}}
{{< gallery-item src="images/Vacuum_mold_6.jpg" caption="" >}}
{{< /gallery >}}

## Pump

You'll need a vacuum pump to draw a vacuum out of your bag. This needs to run
for ~24 hours while your board cures, and it needs to be very reliable, and
ideally quiet.
I used a dedicated vacuum pump built by [Gast](https://www.gastmfg.com) designed
to run 24/7. Simple, small, quiet, easily rebuilt (which we did once.) I kept a
backup on hand, too, just in case. My pump was
model [MOA-V113-AE](https://gastmfg.com/products/moa/moa-v113a-ae). For scale,
these pumps are 8" long.

{{< gallery caption="Gast Vacuum Pump" >}}
{{< gallery-item src="images/PXL_20230831_224411776.jpg" caption="" >}}
{{< gallery-item src="images/PXL_20230831_224349720.jpg" caption="" >}}
{{< /gallery >}}

### Pressure

You hear "vacuum" and think about space: a total vacuum, with no air or
anything. But that's not what you get when you vacuum bag.
It's incredibly difficult to draw a perfect vacuum on Earth. You won't get
anywhere near there.

You measure your vacuum pressure in "inches of mercury (in/Hg)" (in the US). One
atmosphere is 29.92 in/hg.
When vacuum bagging, with a high quality pump, you should expect to draw ~25.5
in/Hg at best. That translates to ~12.5psi across the surface of your board.

Note that the pressure applied to your board varies with the air pressure where
you are, when you do the pressing. It changes with the weather :)

You'll need to get a vacuum gauge to measure the pressure in your bag. Mount it
someplace easy to see, since you'll need to look at it often while trying to get
a good seal on your bag. You should draw your vacuum from one end of the bag,
and measure from the opposite.

## Bagging materials

There are a bunch of disposable materials you'll need:

* **Flat vacuum bag material**. This is a thin, clear plastic which is strong,
  resistant to puncture, but with surprisingly good stretch. I
  used [Stretchlon® 200 Bagging Film](https://www.fibreglast.com/product/stretchlon-200-bagging-film-1678).
  It also won't stick to epoxy, so it releases from your part.
* **Vacuum tape**. This is a special "tape" which you apply to the perimeter of
  your mold, and it's what will adhere the bag to the mold skin and allow you to
  draw a vacuum. There are many kinds, but I always loved
  this [yellow sealant tape](https://www.fibreglast.com/product/yellow-sealant-tape-00580)
  because it is thicker
  than usual and that makes it easier to get a good seal. (I'm using the black
  tape in all these pics, but then I discovered the yellow and never went back.)
* **Breather fabric**. This drapes over the board and allows air to flow evenly
  across the board. It compresses evenly, too, ensuring you have proper pressure
  over the
  entire surface without any trapped air pockets. It will absorb excess resin as
  well.
* **Connectors**.
  [Thru-bag vacuum connectors](https://www.fibreglast.com/product/thru-bag-vacuum-connector-00910)
  allow you to connect your pump and gauge.

## Layup prep

There's a lot of prep, but it's all important. Go carefully and you'll do just
fine. Keeping things clean is critical: you're going to rely on the sealant tape
bonding the
bag to the aluminum *perfectly*, and to do that it all needs to be clean.

1. Clean your mold skin with mineral spirits to ensure it's wax-free.
2. Mark the center line of the mold, and of the board. Ensure you can place the
   base w/ edges in the correct place.
3. Wax your mold skin, leaving a 4" strip under the center of the base and ~2"
   around the edge clean and wax-free.
4. Spray *a little* Super-77 spray adhesive on the clean strip in the center.
   Place your base w/ edges and press it down to adhere to the skin.
5. Apply the sealant tape around the edge of the entire mold skin, in one
   continuous strip. Start in the front center, work your way around carefully,
   and overlap back in the
   front center 4-5". Leave the protective paper on the top of the tape except
   where you have to overlap.
    1. The paper will keep any epoxy drips off of the tape during layup.
    2. **DO NOT STRETCH THE TAPE** while you do this. You want it as thick as
       possible. Stretching will also make the paper come off, which is
       annoying.
6. Tape the bottom half of a thru-bag connector in one corner, with a small
   square of breather fabric underneath. This will be where you draw your
   vacuum.
7. Tape the bottom half of another thru-bag connector in the opposite corner,
   with a small square of breather fabric underneath. This will be where you
   measure your vacuum.
8. Cut strips of breather fabric to fit between the edges of your base and the
   sealant tape. Hold them in place with bits of tape. This will absorb
   squeeze-out from around
   the edges of the board.
9. Cut your bagging material to size, ensuring you have a decent amount of
   overhand all around. Roll it up and set it aside.
10. Cut a sheet of breather fabric, so it fits inside the tape, over the
    board. Make cutouts so you don't cover the thru-bag fittings. Roll it up and
    set it aside.
11. Place your weights (see below) in gallon zip-lock bags. Put them in an
    easily reachable place.
12. Have a roll of paper towels handy.
13. Of course, get all of your board parts ready.

{{< gallery caption="Vacuum Layup Prep" >}}
{{< gallery-item src="images/PC296816.JPG" caption="" >}}
{{< gallery-item src="images/PC296822.JPG" caption="" >}}
{{< gallery-item src="images/PC296823.JPG" caption="" >}}
{{< /gallery >}}

### Pre-bending the core

You will probably find that if you place your core over your base in the mold
that it doesn't sit properly. The core is flat, but your mold isn't.
This isn't a concern with a pneumatic press, where the pressure is so great that
it will bend your core into place perfectly. Depending on the shape of your
mold,
the vacuum pressure may be insufficient to get the core to seat properly against
base at the nose and tail. Also, having the core flat during layup makes it much
harder
to keep the parts aligned.

Thus, I recommend pre-bending the nose and tail of your core. There are a lot of
ways to do this, and I won't go into much detail here.
I did it with a 3" metal pipe, clamped to a workbench and heated with a
blowtorch. I sprayed water on the nose of the core, then worked it against the
hot pipe to steam-bend it.
Ditto for the tail. You have to be very careful to support the nose/tail across
the width of it, so you don't crack it, and you have to work quickly, so you
don't
scorch the
wood or break down the glue holding the core together.

### Weights

Because the core won't conform to the mold, you'll need to weight it down during
layup and while you're getting a vacuum drawn. I recommend two weights, one for
the nose and
one for the tail. I used small, soft workout weights, placed in ziplock bags. I
used about 10lbs per bag. The ziplock bags are disposable, as they will get
covered with epoxy
during layup.

### Top sheet prep

The breather fabric will absorb any resin that squeezes out along the edges of
the board. This is normal. But, it will transport it on top of your top sheet in
places.

So you need to protect the top sheet, at least along the edges, so you don't
glue breather fabric to it. Packing tape, wide protective tape or carpet tape,
etc. can help here.

### Dry-run

Do a dry run, all the way through. Pretend to mix the epoxy, and place the now
sticky cups where you're going to have them. Pretend to pour it.

Place the edge rubber, bottom layer of glass, and your core. Pretend to wet them
out. Place your weights on the nose and tail to force the core into place.

Pretend to wet out the core with the weights in place. Move one weight at a
time, and wet out the rest of core. Now place your top layer of glass, moving
one weight at a
time to get it into place and aligned. Pretend to wet the glass out, again
moving the weights as necessary. Repeat for the top-sheet. This is a pain in the
rear, but you have
get used to it now while you can screw up.

Now place the breather fabric over the board, moving one weight at a time. And
now place the vacuum bag. Get it flat. Picture having gone up to this last step,
and where the epoxy is, and what's on your hands.
You must not get epoxy on the edges of the bag, where it needs to stick to the
tape. And you must not get epoxy on the tape.
You'll need to plan to be clean at this stage, and I'll give more advice below.

Do a few dry runs until you're happy.

## Layup

The moment of truth, when you end up with a board slowly curing under pressure.

1. Mix up your epoxy, and go through the same steps as the dry-run, except the
   last
   step where you place the bag.
2. Be careful about dripping epoxy on the paper covering the sealant tape. A
   little is okay, and it's going to happen. You can wipe it off the paper
   later.
3. Once everything but the bag is in place, take a moment to clean off that
   tape.
4. Get the bag in place, with the paper still on the tape. Keep the weights on
   the nose and tail. Make sure the bag overlaps the tape well.
5. Remove the paper from the tape just along the edge by the nose. Carefully and
   evenly place the bag onto the tape. **Avoid wrinkles!**
6. Now that one end is taped on, look at the bag again and make sure to pull it
   taut along the length of the board.
7. Start removing the paper from the edges, starting at the nose, pulling the
   paper back 6-12" at a time on each side and pressing the bag to the tape
   evenly as you go.
8. Once you have the edges taped on, remove the paper from the tail edge and
   press the bag into place.
9. Cut a small X through the bag over the center of each thru-bag connector.
   Insert
   and close the connectors.
10. Attach one connector to your pump, and the other to your gauge.
11. Turn on the pump and start drawing a vacuum. This won't work well yet, it's
    okay.
12. Now, start working the bag into the tape all the way around. Rub it into the
    tape with your thumb. A piece of paper towel helps to keep from rubbing the
    skin off of your thumb.
    Keep working around the bag, rubbing the bag, tape, and aluminum skin
    together, forming a good seal.
13. At some point you will have made a good enough seal for the vacuum to start
    drawing well. You'll see the air draw out of the bag, everything will press
    down and tighten. You're almost there!
14. Let the vacuum draw for 30s, then look at your gauge. Try to get towards ~25
    in/hg or more. Keep working around the tape looking for any small leaks.
    Wrinkles are leaks every time.
    You can try stretching the bag at a wrinkle and rubbing to get it out.
    Sometimes, you may want to cut another couple inches of tape, and place it
    outside the original line
    to try to get more of a seal. That's fine.
15. Work at the tape until you just can't get any more pressure out of the
    system.
16. Remove the weights, step back, and have a rest.

{{< gallery caption="Vacuum Layup" >}}
{{< gallery-item src="images/PC296822.JPG" caption="" >}}
{{< gallery-item src="images/PC296825.JPG" caption="" >}}
{{< gallery-item src="images/PC296826.JPG" caption="" >}}
{{< gallery-item src="images/PC296827.JPG" caption="" >}}
{{< gallery-item src="images/PC296830.JPG" caption="" >}}
{{< gallery-item src="images/PC296832.JPG" caption="" >}}
{{< gallery-item src="images/PC296836.JPG" caption="" >}}
{{< gallery-item src="images/PC296838.JPG" caption="" >}}
{{< gallery-item src="images/PC296839.JPG" caption="" >}}
{{< gallery-item src="images/PC296840.JPG" caption="" >}}
{{< gallery-item src="images/PC296842.JPG" caption="" >}}
{{< gallery-item src="images/PC296847.JPG" caption="" >}}
{{< gallery-item src="images/PC296848.JPG" caption="" >}}
{{< gallery-item src="images/PC296851.JPG" caption="" >}}
{{< gallery-item src="images/PC296852.JPG" caption="" >}}
{{< gallery-item src="images/PC296853.JPG" caption="" >}}
{{< gallery-item src="images/PC296854.JPG" caption="" >}}
{{< gallery-item src="images/PC296855.JPG" caption="" >}}
{{< gallery-item src="images/PC296856.JPG" caption="" >}}
{{< gallery-item src="images/PC296857.JPG" caption="" >}}
{{< gallery-item src="images/PC296858.JPG" caption="" >}}
{{< gallery-item src="images/PC296859.JPG" caption="" >}}
{{< gallery-item src="images/PXL_20230831_224223823.jpg" caption="" >}}
{{< /gallery >}}

## After layup

Once your board is fully cured (could be 24hrs for a room temp cure), you should
find that the bagging material comes right off.
Hopefully you waxed the mold skin well and the board with all the resin-infused
breather fabric comes off easily. Rip off the clean breather to see the center
of the board.

The breather on the edges will be plasticized. Ideally this comes off of the top
sheet protection you applied pre-layup. The rest will be trimmed off with the
flash.

The board on the right in this pic just came off of the vacuum press.
{{< img src="images/Vacuum_boards.JPG">}}

The tape, bag, and rest of the breather are all garbage now. Don't try to reuse
the bag, it should be hopelessly stuck to the tape anyway. Save the thru-bag
connectors, of course.

## Heat and the hotbox

All epoxy systems cure better with heat. But it's difficult to apply heat when
vacuum bagging.

With pneumatics, we include silicon heat blankets in the stack and get even
heat top and bottom. You can try to do that with bagging, but it's hard. You
have to account for the wires into the bag, it's more to deal with, etc.

Some have used heat lamps along the length of the board. Others have used heat
wire underneath the mold skin.

I build a "hot box" large enough to hold my entire mold setup. Insulated, with a
big door that swung down. I placed the mold on drawer slides, so I could pull it
out about a foot
during layup. I placed 120v silicon heat cable all along the bottom of the box,
under the mold, with terracotta tiles on top of it for thermal mass. I would
preheat the tiles before
layup. I placed a thermocouple on top of the board in the center after I was all
done, then closed up the box. A controller would try to keep the thermocouple at
120F, and it did
a very good job. Once the box was up to temp, it would maintain it well without
much effort over a 24-hour cure.

*Note: these pics show an old vacuum mold.*

{{< gallery caption="Vacuum Hotbox" >}}
{{< gallery-item src="images/Hotbox_overview.JPG" caption="" >}}
{{< gallery-item src="images/Hotbox_open.JPG" caption="" >}}
{{< gallery-item src="images/Hotbox_interior.JPG" caption="" >}}
{{< gallery-item src="images/Hotbox_heat.JPG" caption="" >}}
{{< gallery-item src="images/PXL_20230831_224125744.jpg" caption="" >}}
{{< /gallery >}}

## Vacuum vs Pneumatic

This is somewhat of a "great debate". I believe you can build a fine snowboard
or
ski with vacuum molding. But for top quality results I really do believe you
need to move to pneumatics. I have direct experience moving from vacuum molding
to pneumatics and the results are striking.

* Vacuum pros: a vacuum press is low cost. Materials are readily available from
  multiple suppliers, often locally, and it's easy to get started. The molds are
  much easier to construct.
* Vacuum cons: poor heat transfer, consumable costs add up over time, top sheets
  are often uneven (can mitigate with an additional plate on top, but more
  effort/alignment).
  The laminate isn't as well consolidated (generally poor squeeze out, voids).
  And you have vacuum pump to maintain (and not useful for other things).

* Pneumatic press pros: great pressure application, smooth top sheets, excellent
  squeeze out, excellent heat transfer.

- Pneumatic press cons: expensive to build vs. vacuum. The molds must be beefy
  to take the pressure. Requires a large air compressor.
  There is a small explosion hazard. Air compressor to maintain (though
  generally useful for other things).

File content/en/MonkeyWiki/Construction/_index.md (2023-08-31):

---
dateFromWiki: "2019-02-02T07:42:58Z"
title: "Construction"
aliases:
- /MonkeyWiki/Construction_Overview
- /MonkeyWiki/Construction_Overview/en
weight: 1
bookCollapseSection: true
---
The following articles cover the process of building a snowboard assuming you have the 
[Equipment]({{< ref "MonkeyWiki/Equipment" >}}) and 
[Materials]({{< ref "MonkeyWiki/Materials" >}}) available. 

- Preparation
  - [Construction Checklist]({{< ref "MonkeyWiki/Construction/Preparation/Construction_Checklist.md" >}})
- Core Blank construction
  - [Core blank overview]({{< ref "MonkeyWiki/Construction/Core_blank_construction/Core_blank_overview.md" >}})
  - [Wood selection, drying, and prep]({{< ref "MonkeyWiki/Materials/Wood_selection__drying__and_prep.md" >}})
  - [Building a stack]({{< ref "MonkeyWiki/Construction/Core_blank_construction/Building_a_stack.md" >}})
  - [Slicing a stack]({{< ref "MonkeyWiki/Construction/Core_blank_construction/Slicing_a_stack.md" >}})
  - [Joining the halves of a core blank]({{< ref "MonkeyWiki/Construction/Core_blank_construction/Joining_the_halves_of_a_core_blank.md" >}})
- Core construction
  - [Ash edge stringer and sidewalls]({{< ref "MonkeyWiki/Construction/Core_construction/Ash_edge_stringer_and_sidewalls.md" >}})
  - [Cleanup after inlay, and final blank sizing]({{< ref "MonkeyWiki/Construction/Core_construction/Cleanup_after_inlay__and_final_blank_sizing.md" >}})
  - [CNC Core Cutting]({{< ref "MonkeyWiki/Construction/Core_construction/CNC_Core_Cutting.md" >}})
  - [Final cleanup and sidewall preparation]({{< ref "MonkeyWiki/Construction/Core_construction/Final_cleanup_and_sidewall_preparation.md" >}})
- Laminate preparation
  - [Bases, edges, and nose/tail spacers]({{< ref "MonkeyWiki/Construction/Laminate_preparation/Bases__edges__and_nose_tail_spacers.md" >}})
  - [Inserts and Kevlar backing]({{< ref "MonkeyWiki/Construction/Laminate_preparation/Inserts_and_Kevlar_backing.md" >}})
  - [Top sheet]({{< ref "MonkeyWiki/Construction/Laminate_preparation/Top_sheet.md" >}})
  - [Mold alignment and preparation]({{< ref "MonkeyWiki/Construction/Laminate_preparation/Mold_alignment_and_preparation.md" >}})
- Layup and pressing
  - [Mixing epoxy]({{< ref "MonkeyWiki/Construction/Layup_and_pressing/Mixing_epoxy.md" >}})
  - [Wet layup]({{< ref "MonkeyWiki/Construction/Layup_and_pressing/Wet_layup.md" >}})
  - [Pneumatic Pressing]({{< ref "MonkeyWiki/Construction/Layup_and_pressing/Pneumatic_Pressing.md" >}})
- Finishing
  - [Overview of cleanup and finishing]({{< ref "MonkeyWiki/Construction/Finishing/Overview_of_cleanup_and_finishing.md" >}})
  - [Finishing a wood veneer top sheet]({{< ref "MonkeyWiki/Construction/Finishing/Finishing_a_wood_veneer_top_sheet.md" >}})
  - [Simple screen printing]({{< ref "MonkeyWiki/Construction/Finishing/Simple_screen_printing.md" >}})
  - [Tuning and waxing]({{< ref "MonkeyWiki/Construction/Finishing/Tuning_and_waxing.md" >}})
- Measurement and testing
  - [Weights and fiber fraction]({{< ref "MonkeyWiki/Construction/Measurement_and_testing/Weights_and_fiber_fraction.md" >}})
- [Vacuum Pressing]({{< ref "MonkeyWiki/Construction/Vacuum_Pressing.md" >}})

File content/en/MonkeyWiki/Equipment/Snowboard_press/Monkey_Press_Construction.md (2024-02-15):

---
dateFromWiki: "2019-03-23T07:27:59Z"
title: "Monkey Press Construction"
gallery: true
aliases:
- /MonkeyWiki/Monkey_Press_Construction
- /MonkeyWiki/Monkey_Press_Construction/en
images:
  - images/Press_Full.JPG
weight: 1
---
This is a detailed overview of my pneumatic press, complete with part numbers where applicable. 

{{< img src="images/Press_Full.JPG" caption="_Pneumatic press at Happy Monkey Snowboards, Inc._" >}}The press cavity is 92″ long x 16″ wide x 12″ high. Total press weight is right around 2,000lbs including the molds. There are two 5″ fire hoses which operate between 50-80psi depending on board surface area. There are two heat blankets, one on top and one on bottom, for a total of 3.5W/in^2. The blankets are 14″x85″, 240V for a total draw of 17.35A. It takes about 10 min to heat a board from 70F to 175F.

The mold is adjustable for different effective edge lengths, and different nose/tail lengths and rises. I tend to stick with a single camber block that has yielded good results for us over a broad range of shapes and lengths. I have an ever growing selection of nose/tail blocks. If a new block shape is needed for a particular build then I’ll design a new one and whip it up on the CNC machine.

## Steel 
The press is designed to handle boards up to 200cm long with ease. It’s built out of steel W12x40 I-beams that are 12” high, 8” wide, 9’ long and weigh 40lbs/ft. There are two beams side-by-side on the top and bottom for a cavity width of 16”. The top beams are supported by two 16” long beams turned on their sides for a cavity height of 12”. That puts the total weight of just the I-beam material in the press at 1,547lbs.
 
### Deflection 
{{< img src="images/IMG_20190322_185635.jpg" caption="_Measuring deflection_" >}}
I have used a very common press design, and a frequent concern with this design is how much it deflects under pressure. 

The short answer: 1.1938mm (0.047") in the center @ 50psi. 

That's essentially how much you'll lose in camber on your board or skis due to deflection in this press. I consider this an acceptable tradeoff for the simplicity of the design, both in construction and operation, and if you care it's easily factored into your mold design. I honestly doubt anyone has actually ever cared, given that there's always some difference between the final camber in a board or ski and the actual mold.

Deflection was  measured with a dial indicator set at the center of the bottom beam between the floor and the top flange. Deflection of 0.047" @ 50psi, 0.0405" @ 40psi, and 0.033" @ 30psi. The caliper was checked for square with the flange before measurement, and all measurements were repeatable.

I also took measurements from the top with a mount for a dial indicator screwed to the wall behind the press. Measuring the center, and the ends, resulted in a center deflection within 0.003" of the measurement taken from the bottom. The measurements on the ends allowed me to see the lift of the upper section as a whole as well, which was on the order of 0.45mm (0.0179").

## Frame Assembly 
 
{{< img src="images/Press_Bolts.JPG" caption="_Bolts holding the frame together._" >}}The press is assembled with 1/2″ Grade 8 nuts and bolts. This is a simple, cost effective way for anyone to put a press like this together and get a reliable joint. Welding is another option, but it takes a very skilled welder to produce the proper joint to withstand the pressure generated by the hose. If you’re a good welder, or know one, then that’s a reasonable way to go, and is a lot less drilling. But if you’re not, then a weekend’s rental of a mag drill (less than $100, including the drill bits you’ll chew thru) and $35 for the nuts, bolts, and washers is the solid way to go. You also end up with a press that comes apart, which may be useful depending on your workspace and whether or not you ever need to move the press. 

Part numbers: [91257A748](http://www.mcmaster.com/#91257A748), [94895A825](http://www.mcmaster.com/#94895A825), and [98023A033](http://www.mcmaster.com/#98023A033).
 
I put the press on casters, and although the final weight with everything in it is right around 2,000lbs, it’s easy to move. Part numbers [22955T42](http://www.mcmaster.com/#22955T42) and [22955T36](http://www.mcmaster.com/#22955T36).

I torque the frame bolts to 40ft lbs to ensure that all of the bolts are under pretty much equal tension once the press is pressurized. There is nothing scientific about the choice of torque, it is just something that felt reasonably tight using a normal crescent wrench. The only goal is that they are all the same.

## Pneumatics 
 
{{< img src="images/Press_AirControl.JPG" caption="_Air control on the Monkey Press._" >}}A little time spent on the air system pays off in simplicity and reliability in the long-term. There’s a little bit of soldered copper piping in the system, but that’s really just for the long runs, and it’s completely optional. The rest is made up of standard brass fittings put together with a little Teflon tape. (Tip: get the yellow stuff designed for natural gas applications. It’s a little thicker and seals more easily.)
 
Airflow to the bladders is controlled with a hand-operated lever air control valve, 4-way, 3-position, closed center. Part number [3368K26](http://www.mcmaster.com/#3368K26). It’s hooked up so that when the lever is in the center, no air flows. When the lever is to the right, air flows into the bladders, and when the lever is to the left air flows from the bladders out the exhaust.
 
The exhaust is muffled with a simple sintered bronze exhaust muffler, part number [4450K2](http://www.mcmaster.com/#4450K2). It’s about $2 and completely worth it to save your hearing.
 
Overall pressure to the system is limited to 90psi with a simple brass pop-safety valve, part number [48435K72](http://www.mcmaster.com/#48435K72).
 
There is a pressure gauge and pressure regulator on the input side and a gauge on the bladder side to monitor the actual bladder pressure when the valve is closed.
 
{{< img src="images/Press_BladderInputConnector.JPG" caption="_Press-to-bladder disconnect._" >}}{{< img src="images/Press_UpperAirConnector.JPG" caption="_Shop air-to-press disconnect._" >}}There’s a quick connect on the input side that matches the rest of the air tools in the shop, so a standard shop air supply hooks up to the press. There’s also a similar quick connect from the press frame to the flexible hose for the bladders to allow the bladders to be removed when necessary. This also hooks directly to shop air, just in case.

The single best guide I’ve found for how to solder copper pipe is [Soldering and Brazing Copper Tube and Fittings](http://www.copper.org/publications/pub_list/pdf/soldering_brazing_ads.pdf), directly from the Copper Development Association, Inc.

## Bladder Connections 
 
People usually have a lot of trouble constructing leak free bladders. They usually seem to end up with a lot of “goop” involved in an effort to stop leaks at the ends and at the through couplings. The bladders in my press are essentially leak free to 90psi with only Teflon tape.
 
The ends are held together with standard 1″ angle iron from Home Depot using seven 3/8″ Grade 8 bolts: two on the outside ends, one in between the hoses, and two through each hose. They’re torqued down pretty snug, but we didn’t kill ourselves tightening them. No silicon sealant, plumber’s goop, etc., and no leaks.
 
The through couplings were more of a challenge. We went through a few tests before settling on what you see below. If you look closely at the full sized image you’ll see a little soapy water around most of it. This picture was taken with the bladders at 90psi. Again, no goop. The secret here is the combination of the three kinds of washers, and the simple fact that the nut for the panel mount coupling is on the outside of the bladder. The washer configuration is repeated on the inside. The 1/8″ thick rubber washers are against the bladder, then the steel, then the Aramid/Buna-N between the steel and the brass nuts. The result is a great seal with the bladder, and a great seal to the nuts. This is not super-tight… just snug, with a little deformation in the rubber washer visible during assembly.
 
The steel washers are the standard 3/4″ washers from Home Depot. Here are the other parts and the McMaster-Carr part numbers:

- Med-Pressure Extruded Brass Thrd Pipe Fitting 1/4″ Pipe Size, Panel Mount Coupling, [50785K273](http://www.mcmaster.com/#50785K273)
- 3/4″ Screw Size, 2″ Od, 1/8″ Thick Large-Od Extra-Thick Reinforced Rubber Washer (10), [90131A106](http://www.mcmaster.com/#90131A106)
- Aramid/Buna-N Washer 3/4″ Id, 1-1/2″ Od, .0625″ Thick (5), [93303A317](http://www.mcmaster.com/#93303A317)
 
These parts aren’t super-cheap, but they’re completely worth it.

{{< gallery  caption="Bladder connections" >}}
{{< gallery-item src="images/Press_BladderConnections.JPG" caption="A view of the air connections to the two fire hoses on the Monkey Press." >}}
{{< gallery-item src="images/Press_BladderConnectionDetail.JPG" caption="A close up view of the way I supply air to my fire hose bladders on the Monkey Press." >}}
{{< /gallery >}}

## Layers 
 
All aluminum used for mold skins is 0.032” 5052-H32 aluminum that I get from [Alaskan Copper & Brass Company](http://www.alaskancopper.com/) here in Seattle. From top to bottom I have the following: 

- top MDF mold and 2×4 fillers.
- bladder
- 1”x16” steel cat track bars
- top heat assembly
  - one aluminum skin
  - top heat blanket
  - one aluminum skin
- board assembly
  - aluminum top mold skin
  - snowboard
  - aluminum base mold skin
- bottom heat assembly
  - one aluminum skin
  - bottom heat blanket
  - one aluminum skin
- MDF mold
 
This allows for easy insertion of the board into the press after wet layup.
 
Each assembly is held together with a very simple system: 4 holes are drilled near the edges of the aluminum skins, two on each side, and the two sheets of aluminum with either a heat blanket or the laminate are held together with small lengths of 12awg copper wire, or with zip ties. You can see these poking out the sides in some of the pictures.

## Cat track suspension 
 
{{< img src="images/Press_TrackSuspension.JPG" caption="_Track suspension on the Monkey Press._" >}}The cat track is suspended with simple bungee cord, bought in bulk from McMaster-Carr. [8858T21](http://www.mcmaster.com/#8858T21), 100’, red.

## Design Flaws 
In this design the flanges of the I-beams are bolted together, and placed under tension. This means that the flanges of the beams are being used to support the load created by the bladders in between them, and this is not how I-beams are designed to be used. There is a risk that the flange could separate from the web under sufficient pressure. However, with large I-beams this design has proven to work well for me and others over many, many years and press cycles. 

Nevertheless, this is a fair criticism of the design, and I encourage anyone who wants to build their own press to consider this, and consult with an engineer to validate the design of your own press.

There are alternative designs which do not suffer from this flaw, and more properly support the upper and lower beams from the outside, rather than holding them together from the inside. 

## See Also 
- [Press heat control and thermocouples]({{< ref "MonkeyWiki/Equipment/Snowboard_press/Press_heat_control_and_thermocouples.md" >}})

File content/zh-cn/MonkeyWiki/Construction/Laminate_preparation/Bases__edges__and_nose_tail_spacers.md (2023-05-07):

---
dateFromWiki: "2019-04-16T08:46:51Z"
title: "板底, 边刃, 板头和板尾垫片"
gallery: true
aliases:
- /MonkeyWiki/Bases,_edges,_and_nose_tail_spacers/zh-cn
- /MonkeyWiki/Bases,_edges,_and_nose/tail_spacers/zh-cn
translatedDate: "2019-04-16T08:46:51Z"
translator: "X z"
translatorPage: "/zh-cn/MonkeyWiki/X_z"
---
带有边刃的板底定义了滑雪板的最终形状。在层压后修剪板时，边刃用作引导。板头和板尾垫片用于板头和板尾上的边墙。这些超出了滑雪板的有效边刃的范围。

## 板底

从辊上切下一段长度的板底，比所需的长一点。然后，用夹子将这种材料固定到位，并在CNC机床上切出形状。板底切割尺寸比整个滑雪板尺寸小2mm。这允许2mm宽的边刃材料限定板底的最终形状。

在CNC机床上保持板底相当简单。我将板底夹紧，就像我的空白板芯一样：沿着每边的长度夹住几个。机器开始在板头处切割并在一侧向下通过。当它围绕板尾转弯并开始切割第二侧时，我开始用手稳定切割板底。当刀具再次接近板头时，我确保一只手放在板底中间，另一只手靠近切割头。我发现通过这种方式完全保持板底很容易。替代品可能是双面胶带，当然还有一个像样的真空吸尘器，但是因为只是把它压低对我来说效果很好我从未有过足够的动力来尝试别的东西。 

板底采用1/4英寸，双刃直刀切割，我们仅保留切割板底和板头/板尾垫片材料。这使其保持锋利，从而在切割的板底上产生更好的光洁度。我使用两种板底之一：ISOSPORT 7500或ISOSPORT ISOHIGHSPEED 2112，两者都是黑色烧结PTEX。ISOHIGHSPEED是一个含有10％石墨的竞赛板底，经过多年的努力，我们一直在测试这两种材料。

刀具总是在板底边缘留下一点“毛刺”。我从来没有找到一个可以防止这种情况的刀具。我用一块小木块上的320目砂纸去除了毛刺。它可以轻松地磨掉毛刺材料，而不会改变底板的形状。

## 边刃准备

边刃材料由钢制成。它的洛氏硬度为HRC 48，这是行业标准。我有一些预切割成84英寸(约213cm)长度的边刃材料。它在工厂进行喷砂处理以帮助粘接。对于长达185cm的板，这是一个很好的长度，具体取决于板的形状。对于比这更长的板，我从连续的原材料卷材切割边刃材料，这些材料是未加工的，未进行粘合处理。然后，我使用一个小型喷砂机对这些边刃进行喷砂处理，我可以在需要时在我们的商店中进行处理。

我很擅长在边刃材料上做好表面处理。我非常小心地检查两种类型的边缘并标记任何可以使用改进的地方，然后再次通过喷砂机对它们进行任何必要的点修补。在此之后，我只戴着手套操作边刃，以确保我皮肤上的油不会污染边刃表面。

我使用60目的氧化铝喷砂介质。喷射单一长度的边刃材料大约需要10分钟。

{{< gallery  caption="边刃喷砂" >}}
{{< gallery-item src="images/Edges_Blasting1.JPG" caption="Blasted edges with marks to indicate further work." >}}
{{< gallery-item src="images/Edges_Blasting2.JPG" caption="Blasted edges with marks to indicate further work." >}}
{{< gallery-item src="images/Edges_Blasting3.JPG" caption="The blasting setup. A length of edge is fed through a small hole on either side of the cabinet. Note the roll of edge material in the lower right." >}}
{{< gallery-item src="images/Edges_Blasting4.JPG" caption="Interior of the blast cabinet showing the supports used while blasting an edge. The edges are pretty flexible over any reasonable distance, so the supports are needed to keep the edge stable for a consistent surface finish." >}}
{{< gallery-item src="images/Edges_Blasting5.JPG" caption="A comparison of a blasted edge (left) and a raw unblasted edge from our roll (right)" >}}
{{< /gallery >}}

## 边刃弯曲和固定到板底

接下来，弯曲边刃以完美匹配板底的形状。我首先通过[弯边机]({{< ref "MonkeyWiki/Equipment/Snowboard-specific_tools/Edge_Benders.md" >}})折弯边刃的末端，然后用手精练其余的弯曲。这个初始弯曲有很大帮助，我试图使它比实际需要的更紧，因为它似乎更容易放松回到正确的形状。任何超出板中心线的多余边刃都会被修剪掉并归档。一旦边刃完美贴合，我将其夹紧并用氰基丙烯酸酯胶（Super Glue）暂时固定到位。当板层压时，环氧树脂在边刃和板底以及层压板的其余部分之间提供最终粘合。

有时它会很快，但通常需要大约2个小时才能完全封边，包括胶水上的干燥时间。如果我需要一个特别紧的弯曲，或者做一个扭结或得到完美的结果我将使用[[Special：MyLanguage/Edge Benders|改装钳]]在我需要的地方施加力。

这是一个将边刃应用于板底的简短视频。它的细节很少，但它会让你了解整个过程。

{{< youtube AkbyyPXv0go >}}

注意：超级胶水不会像你期望的那样立即粘合。它需要大约20分钟才能干燥并保持边刃，但一旦干燥它就能保持良好状态。 

我准备了一个简短的视频，展示了如何将胶水涂在边刃上，我希望会有所帮助。

{{< youtube CztMsfW4v78 >}}

{{< gallery  caption="弯曲边刃" >}}
{{< gallery-item src="images/Edges_Bending1.JPG" caption="A length of edge fit to the base and held in place with a few clamps until the glue dries. Note that the glue has already been applied to the edges and base here. It only takes a small drop on each side of each clamp to hold the edge in place for the rest of the process, and the glue does not get in the way of the bond with the epoxy later." >}}
{{< gallery-item src="images/Edges_Bending2.JPG" caption="A length of edge fit to the base and held in place with a few clamps until the glue dries. Note that the glue has already been applied to the edges and base here. It only takes a small drop on each side of each clamp to hold the edge in place for the rest of the process, and the glue does not get in the way of the bond with the epoxy later." >}}
{{< gallery-item src="images/Edges_Bending5.JPG" caption="A length of edge fit to the base and held in place with a few clamps until the glue dries. Note that the glue has already been applied to the edges and base here. It only takes a small drop on each side of each clamp to hold the edge in place for the rest of the process, and the glue does not get in the way of the bond with the epoxy later." >}}
{{< gallery-item src="images/RingRoller5.JPG" caption="" >}}
{{< gallery-item src="images/RingRoller1.JPG" caption="" >}}
{{< gallery-item src="images/Nippers2.JPG" caption="" >}}
{{< gallery-item src="images/Nippers6.JPG" caption="" >}}
{{< /gallery >}}

## 板头和板尾垫片

我将PTEX用于板头和板尾垫片。沿着板头和板尾的板芯周边需要这种额外的材料。它具有与PTEX边墙类似的用途 - 它可以随着时间的推移保护板芯。这种材料在两面都是滚动，打磨和火焰，准备好粘接。我在CNC机器上将其切割成形状，使其与板芯完美匹配，并用一小块薄纸带暂时将其固定到位。我在PTEX的板头和板尾留出的空间比我们在边墙上的空间多一点，主要是因为那里的板子更薄，并且需要更多的空间。

注意：有些人在使用这样的胶带时遇到了麻烦。胶带确实留在层压板内部，我从来没有遇到过这个问题。然而，有些人使用类似的胶带，并在顶片下面产生小气泡。固定这些部件的替代方案包括在层压板外面的钉书钉，使用轻质玻璃编织层叠它们的额外步骤等。

{{< gallery  caption="垫片" >}}
{{< gallery-item src="images/NoseTailSpacers1.JPG" caption="Nose and tail spacers." >}}
{{< gallery-item src="images/NoseTailSpacers2.JPG" caption="Nose and tail spacers." >}}
{{< /gallery >}}

## 参阅

- [弯边机]({{< ref "MonkeyWiki/Equipment/Snowboard-specific_tools/Edge_Benders.md" >}})

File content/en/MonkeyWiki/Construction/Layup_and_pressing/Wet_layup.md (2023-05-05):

---
dateFromWiki: "2019-03-23T19:56:28Z"
title: "Wet layup"
aliases:
- /MonkeyWiki/Wet_layup
- /MonkeyWiki/Wet_layup/en
weight: 2
---
# Raw Notes
This is a temporary page containing raw, unedited notes on this subject. This page and the information here is incomplete, and may be inaccurate. 

- Start with how I do wet layup for a snowboard.
- Make a full video of layup.
- Prep (see checklist), dry run, marking materials for fit, etc.
  - Dry layup first!! Focus on alignment of all pieces, anything that interferes with your cassette system or vacuum hookups, etc.
- Spreaders
- Wetting glass
- Amount to use in different areas
- Wetting base and edge tines, rubber, placing rubber.
- Placing the first layer of glass, adding more in dry places, ensuring an even spread and not leaving large pools of epoxy between layers.
- Inserts and Kevlar, placing the core, maintaining core alignment.
- Placing auxiliary reinforcements.
- Placing the second layer of glass. 
- Placing the topsheet.
- Closing the cassette and ensuring things stay in alignment during insertion.
- Cleanup.

Resources on wet layup in general: articles online, etc.

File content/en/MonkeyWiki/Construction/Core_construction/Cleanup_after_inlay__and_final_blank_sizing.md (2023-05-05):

---
dateFromWiki: "2019-02-13T04:12:02Z"
title: "Cleanup after inlay, and final blank sizing"
gallery: true
aliases:
- /MonkeyWiki/Cleanup_after_inlay,_and_final_blank_sizing
- /MonkeyWiki/Cleanup_after_inlay,_and_final_blank_sizing/en
---
After the glue has dried, the core blank has to be cleaned up quite a bit. The excess glue must be scraped away, and the blank has to be smoothed completely on both sides using a planer. In order to get a good first pass out of the planer, any high spots on the ash and PTEX need to be shaved down by hand with a block plane. Once the blank is finished in the planer, the base side is pretty much finished. No further smoothing is done on it, and it must be perfectly flat. I take great care to keep the planer in good working order, and I make sure the final passes on the base side are light. This gives me a high quality finish.
 
I love the way our blanks look at this stage. They’re perfectly smooth, and the PTEX and 2cm ash along the effective edge is perfectly smooth. It’s usually at this point that I get sad that the beauty of these cores is obscured in the final product.

After this step, the blank is still thicker than the final thickness of the board. The thickness profile will be applied by the CNC machine in a later step.
 
The planer I use is a JET 15” planer, which is wide enough to accommodate the width of a snowboard core blank. You could use a smaller planer if you’re making skis.

Here is a short video which shows each step of shaping a core from blank to final core, including inlay, cleanup, and final blank sizing.

{{< youtube pQZlsaCv4dY >}}

{{< gallery  caption="Cleanup of sidewall inlays and final core blank thickness" >}}
{{< gallery-item src="images/CoreBlank_InlayCleanup4.JPG" caption="Core blank out of the clamps with lots of expanded polyurethane glue. It is scraped off, and a block plane is used to take down any high spots on the cleanest side to prepare for the mechanical planer." >}}
{{< gallery-item src="images/CoreBlank_InlayCleanup5.JPG" caption="Core blank out of the clamps with lots of expanded polyurethane glue. It is scraped off, and a block plane is used to take down any high spots on the cleanest side to prepare for the mechanical planer." >}}
{{< gallery-item src="images/CoreBlank_InlayCleanup1.JPG" caption="Core blank with PTEX and ash inlay being planed." >}}
{{< gallery-item src="images/CoreBlank_InlayCleanup2.JPG" caption="Core blank with PTEX and ash inlay being planed." >}}
{{< gallery-item src="images/CoreBlank_InlayCleanup3.JPG" caption="Core blank with PTEX and ash inlay being planed." >}}
{{< gallery-item src="images/CoreBlank_InlayCleanup6.JPG" caption="Blank ready for final shaping on the CNC machine." >}}
{{< gallery-item src="images/CoreBlank_InlayCleanup7.JPG" caption="Detail of the PTEX and ash inlay." >}}
{{< gallery-item src="images/CoreBlank_InlayCleanup8.JPG" caption="Detail of the PTEX and ash inlay." >}}
{{< /gallery >}}

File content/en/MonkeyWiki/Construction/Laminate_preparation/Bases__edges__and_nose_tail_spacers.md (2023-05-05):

---
dateFromWiki: "2019-02-13T03:51:42Z"
title: "Bases, edges, and nose/tail spacers"
gallery: true
aliases:
- /MonkeyWiki/Bases,_edges,_and_nose/tail_spacers
- /MonkeyWiki/Bases,_edges,_and_nose/tail_spacers/en
weight: 1
---
The base, with the attached edges, defines the final shape of the board. The edges are used as a guide when trimming the board out after lamination. The nose and tail spacers serve the purpose of sidewalls on the nose and tail. These areas are beyond the effective edge of the board.

## Bases 
 
A length of base material is cut off of a roll just a little bit longer than necessary. Then, this material is held in place with clamps and the shape cut out on the CNC machine. The base is cut 2mm smaller than the overall board size all the way around. This allows the edge material, which is 2mm wide, to define the final shape for the base.

Holding the base material while the CNC machine is fairly simple. I clamp the base material down much like I do the core blanks: a few clamps along the length of each side. The machine starts cutting at the nose and makes a pass down one side. As it makes the turn around the tail and starts cutting the second side I start to stabilize the cut base by hand. As the cutter approaches the nose again I make sure to have one hand at the middle of the base and one close to the cutting head. I’ve found it’s easy to hold the base completely still this way. Alternatives might be double-sided tape, and of course a decent vacuum table, but since just holding it down has worked so well for me I’ve never been motivated enough to try something else. 

The base is cut with a 1/4″, two flute, straight cut bit that we reserve only for cutting base and nose/tail spacer material. This keeps it sharp, which yields a better finish on the cut base material. I use one of two base materials: ISOSPORT 7500 or ISOSPORT ISOHIGHSPEED 2112, both of which are black, sintered PTEX. The ISOHIGHSPEED is a race base with 10% graphite, proven to be consistently faster over the many years we’ve been testing with these two materials.

The cutter always leaves a little bit of “fuzz” around the edge of the base. I’ve never found a cutter that prevents this. I remove the fuzz with some 320 grit sandpaper attached to a small wood block. It knocks the fuzzy material off easily without changing the shape of the base.

## Edge preparation 
 
Edge material is constructed from steel. It has a Rockwell hardness of HRC 48, which is the industry standard. I have some edge material that is pre-cut in 84” lengths. It is sandblasted at the factory to aid with bonding. This is a good length to work with for boards up to about 185cm long, depending on the shape of the board. For boards longer than that, I cut edge material from a continuous roll of material that is raw and has not been treated for bonding. I then sandblast these edges using a small sandblasting rig that I can set up in our shop when needed.
 
I’m pretty anal about good surface preparation on the edge material. I check over both types of edges very carefully and mark any places that could use improvement, then send them through the sandblaster again for any necessary spot touch-up. After this, I only work with the edges while wearing gloves to ensure I don’t contaminate the edge surface with any oil from my skin.
 
I use a 60 grit aluminum oxide blasting media. It takes about 10 minutes to blast a single length of edge material.

{{< gallery  caption="Sandblasting edges" >}}
{{< gallery-item src="images/Edges_Blasting1.JPG" caption="Blasted edges with marks to indicate further work." >}}
{{< gallery-item src="images/Edges_Blasting2.JPG" caption="Blasted edges with marks to indicate further work." >}}
{{< gallery-item src="images/Edges_Blasting3.JPG" caption="The blasting setup. A length of edge is fed through a small hole on either side of the cabinet. Note the roll of edge material in the lower right." >}}
{{< gallery-item src="images/Edges_Blasting4.JPG" caption="Interior of the blast cabinet showing the supports used while blasting an edge. The edges are pretty flexible over any reasonable distance, so the supports are needed to keep the edge stable for a consistent surface finish." >}}
{{< gallery-item src="images/Edges_Blasting5.JPG" caption="A comparison of a blasted edge (left) and a raw unblasted edge from our roll (right)" >}}
{{< /gallery >}}

## Edge bending and tacking to the base 
 
Next, I bend the edges to match the shape of the base material perfectly. I start by running the ends of the edge through a [Edge Benders]({{< ref "MonkeyWiki/Equipment/Snowboard-specific_tools/Edge_Benders.md" >}}), then finesse the rest of the bending by hand. This initial bend helps a lot, and I try to make it tighter than it really needs to be since it seems to be easier to relax it back to the proper shape. Any excess edge that extends past the centerline of the board is trimmed off and filed. Once the edge fits perfectly, I clamp it down and tack it temporarily in place with cyanoacrylate glue (Super Glue). When the board is laminated, epoxy provides the final bond between the edges and the base material, as well as to the rest of the laminate.
 
This part of the process is fairly painstaking. Sometimes it goes quickly, but often it takes about 2 hours to edge a base completely, including drying time on the glue. If I need an especially tight bend, or to work a kink out or get the very ends perfect I’ll use a [Edge Benders]({{< ref "MonkeyWiki/Equipment/Snowboard-specific_tools/Edge_Benders.md" >}}) to apply force exactly where I need it.

Here's a short video of applying edges to a base. It's low on detail, but it'll give you an idea of the process.

{{< youtube AkbyyPXv0go >}}

Note: the super glue doesn’t bond immediately like you would expect. It takes about 20 min for it to dry and hold the edge on, but once it does dry it holds extremely well. 

I've prepared a brief video showing how I apply the glue to the edges that I hope will be helpful.

{{< youtube CztMsfW4v78 >}}

{{< gallery  caption="Bending edges" >}}
{{< gallery-item src="images/Edges_Bending1.JPG" caption="A length of edge fit to the base and held in place with a few clamps until the glue dries. Note that the glue has already been applied to the edges and base here. It only takes a small drop on each side of each clamp to hold the edge in place for the rest of the process, and the glue does not get in the way of the bond with the epoxy later." >}}
{{< gallery-item src="images/Edges_Bending2.JPG" caption="A length of edge fit to the base and held in place with a few clamps until the glue dries. Note that the glue has already been applied to the edges and base here. It only takes a small drop on each side of each clamp to hold the edge in place for the rest of the process, and the glue does not get in the way of the bond with the epoxy later." >}}
{{< gallery-item src="images/Edges_Bending5.JPG" caption="A length of edge fit to the base and held in place with a few clamps until the glue dries. Note that the glue has already been applied to the edges and base here. It only takes a small drop on each side of each clamp to hold the edge in place for the rest of the process, and the glue does not get in the way of the bond with the epoxy later." >}}
{{< gallery-item src="images/RingRoller5.JPG" caption="" >}}
{{< gallery-item src="images/RingRoller1.JPG" caption="" >}}
{{< gallery-item src="images/Nippers2.JPG" caption="" >}}
{{< gallery-item src="images/Nippers6.JPG" caption="" >}}
{{< /gallery >}}

## Nose and tail spacers 
 
I use PTEX for nose and tail spacers. This extra material is needed along the perimeter of the core at the nose and the tail. It serves a similar purpose to the PTEX sidewalls - it protects the core over time. This material comes to us on a roll, sanded and flamed on both sides, ready for bonding. I cut it to shape on the CNC machine so it matches the core perfectly, and temporarily hold it in place with small pieces of a thin tape made mostly of paper. I leave a little more room on the nose and tail for PTEX than we do on the sidewall mostly because the board is thinner up there, and takes a little more abuse.

Note: Some people have had trouble using tape like this. The tape does remain inside of the laminate, and I’ve never had a problem with that. However, some people have used similar tape and had it cause small bubbles under the top sheet. Alternatives to holding these pieces on include staples just outside the laminate, an extra step to laminate them on with a light weave of glass, etc.

{{< gallery  caption="Spacers " >}}
{{< gallery-item src="images/NoseTailSpacers1.JPG" caption="Nose and tail spacers." >}}
{{< gallery-item src="images/NoseTailSpacers2.JPG" caption="Nose and tail spacers." >}}
{{< /gallery >}}

## See Also 
- [Edge Benders]({{< ref "MonkeyWiki/Equipment/Snowboard-specific_tools/Edge_Benders.md" >}})

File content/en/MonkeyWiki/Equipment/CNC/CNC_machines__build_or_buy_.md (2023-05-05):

---
dateFromWiki: "2019-02-03T02:37:57Z"
title: "CNC machines: build or buy?"
aliases:
- /MonkeyWiki/CNC_machines:_build_or_buy_
- /MonkeyWiki/CNC_machines:_build_or_buy_/en
- /MonkeyWiki/CNC_machines:_build_or_buy
- /MonkeyWiki/CNC_machines:_build_or_buy/en
- /MonkeyWiki/CNC_machines:_build_or_buy?
- /MonkeyWiki/CNC_machines:_build_or_buy?/en
weight: 3
---
People frequently ask me if they should build their own CNC machine like the [CNC Router]({{< ref "MonkeyWiki/Equipment/CNC/CNC_Router.md" >}}) or just buy one. I don’t necessarily want to discourage anyone, but it really comes down to how much time and energy you want to spend building the machine versus how much time you want to spend making use of the machine. Presumably, you want a CNC machine to help you perform some interesting task, after all!
 
Building your own CNC machine is fun, and you learn a lot doing it. But you should go into the endeavor with your eyes open regarding what you’re getting into.
 
First, I’m going to assume that you want to build a large table CNC router that is on par with the reasonable low-end of CNC routers on the market today, like the base model [Shopbot](http://www.shopbottools.com/). There are lots of other options, though, like desktop machines with smaller cutting areas, or much lower precision machines built out of MDF and plastic that are great for many projects and a good way to learn about CNC at a low cost. I have no experience with either of these alternatives, so I’ll limit myself to precision CNC routers.
 
My goal was to build a machine that was accurate with repeatable positioning to within +/-0.005”, and which will stand up to years of use with reasonable maintenance. It should be rigid enough to cut half inch MDF or poplar at a reasonable rate, say 100 IPM, hold a 2-3hp router, and spin bits up to 1.5” in diameter. You should first establish similar goals for yourself: determine what precision you need, what materials you want to cut, and how fast you want to cut them. Use specifications on commercial CNC machines as a guide.
 
It’s not necessarily that much cheaper to build a good CNC machine than it is to buy a good one from outfits like Shopbot. It cost me just under $6,000 to build my machine in 2003, and at the time I could have bought a machine from Shopbot that was just as accurate, and a bit faster, for a little less than $8,000. Frankly, the difference in price was justified: the Shopbot had a more rigid frame, larger motors, etc. I also saved a reasonable amount of money buying some of the parts off of eBay. The components that go into it are not cheap, particularly the stepper motors, linear slides, and the framing material. These are three areas that you should not skimp on at all if you decide to build one yourself. However, these are the three that I frequently see people try to save a buck on, which only makes them sad later.
 
Building an accurate, rigid CNC machine takes a lot of time and precision metal work. At some point you will require the help of someone with at least a manual knee mill to flatten various mounting plates, and drill very accurate holes in key areas. The more precise you attempt to make the machine, the more precise you must be in machining the parts. Many materials are not actually flat when you get them, even though to the naked eye they might appear flat. Quality linear slides must be mounted to very flat surfaces or they will warp when the bolts are tightened down. This will cause the bearings will bind and nothing will move. Some background in precision machining is essential to constructing a good CNC router.
 
You’ll also need some background in basic electronics. These machines easily draw 30A at 220v between all the motors, drivers, and the controller. You should be comfortable working with both high voltage AC and low voltage DC.
 
If you do decide to build your own machine, I highly recommend two things:
1. Look for a precision machining course at a local community or technical college. I took two courses in precision machining in the evenings at [Lake Washington Technical College](http://www.lwtc.edu/), which were excellent. Without them, I surely would have failed to build my first machine.
1. [CNC Zone](http://www.cnczone.com/). This is a fantastic community of DIY CNC builders, with resources for materials and components, advice on design and construction, etc.

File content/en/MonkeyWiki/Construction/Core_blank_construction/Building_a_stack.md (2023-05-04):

---
dateFromWiki: "2019-02-03T02:14:02Z"
title: "Building a stack"
gallery: true
aliases:
- /MonkeyWiki/Building_a_stack
- /MonkeyWiki/Building_a_stack/en
weight: 2
---
Once the boards are ready to go, the next step is to sort through them and find nine that make a reasonable stack. The boards don’t have to be perfectly straight. If they are all bent in the same way, that's fine.  If the stack is a bit bowed end-to-end, we can correct that later. 

When selecting boards to form a stack, it's important that they all be as similar as possible. The broad sides should be as close to smooth as you can get them. We’ll make them perfectly smooth later, so the smoother they are at the beginning, the less waste there will be later.

{{< gallery  caption="Matching boards into individual stacks." >}}
{{< gallery-item src="images/Stack_Matching_Raw.JPG" caption="Poplar boards that need to be matched up into stacks." >}}
{{< gallery-item src="images/Stack_Matching_In_Progress.JPG" caption="Selecting boards with similar bend to become stacks." >}}
{{< gallery-item src="images/Stack_Matching_One_Done.JPG" caption="One stack of nine boards ready to go." >}}
{{< /gallery >}}

Once you have a set of boards ready to go, lay them out on a bench in the order and orientation that you’ll be needing them during glue up. 

I use 8 [Pipe Clamps]({{< ref "MonkeyWiki/Equipment/Small_tools/Pipe_Clamps.md" >}}), each with 12” wide 2” x 2” oak cauls on each side. I will alternate these on each side of the stack as I clamp it, so I start with half of the clamps on my workbench spaced to ensure that the other half wont overlap them much. I place butcher's paper under the clamps to protect the workbench from dripping glue.

A fine spray of clean water on the boards adds a bit of moisture, which will help the glue cure properly.

{{< gallery  caption="A stack ready for layup." >}}
{{< gallery-item src="images/Stack_Layup_Ready.JPG" caption="Nine boards ready for stack layup, spread out to allow a bit of water to help with the glue cure later." >}}
{{< gallery-item src="images/Stack_Layup_Water.JPG" caption="Spraying water on the boards to help the glue cure later." >}}
{{< /gallery >}}

I use Polyurethane glue for my stacks because it has a reasonably long working time. It will take about 15 min to actually get a single stack clamped up. I take the cap off the bottle and pour a bead of glue down the entire length of the first board. Then, I spread it with a plastic spreader the same way I spread epoxy during layup. (I use old bits of base material as a spreader here.) 

It takes some practice to start to recognize how much glue to apply in a single pass. Start with too little and add more but don’t take too much time as there are seven more applications to make. Take the next board and lay it in place on top of the first one, then rinse and repeat. Once the final board is in place, you’ll have a gooey stack ready to be clamped. 

{{< gallery  caption="Applying glue to a stack." >}}
{{< gallery-item src="images/Stack_Layup_Glue_Pour.JPG" caption="Pouring glue during stack layup." >}}
{{< gallery-item src="images/Stack_Layup_Spreding.JPG" caption="Spreading glue with a bit of scrap base material as a spreader." >}}
{{< gallery-item src="images/Stack_Layup_Second_Board.JPG" caption="Adding the second board to the stack." >}}
{{< gallery-item src="images/Stack_Layup_Third_Board.JPG" caption="Adding the third board to a stack." >}}
{{< gallery-item src="images/Stack_Layup_Final_Board.JPG" caption="Adding the final board to the stack." >}}
{{< /gallery >}}

Carefully push the stack over so it lays flat on the bottom set of clamps. Adjust the board placement as necessary. Note that the ends of the stack don’t have to align perfectly! It’s common to have boards of slightly different lengths and that’s okay; we’ll trim it up later.

{{< gallery  caption="Laying down the stack for clamping." >}}
{{< gallery-item src="images/Stack_Layup_Laydown1.JPG" caption="Laying a stack down before clamping." >}}
{{< gallery-item src="images/Stack_Layup_Laydown2.JPG" caption="Laying a stack down before clamping." >}}
{{< gallery-item src="images/Stack_Layup_Laydown3.JPG" caption="Laying a stack down before clamping." >}}
{{< /gallery >}}

Once the boards are aligned, tighten the center clamp on the bottom. Then, add top clamps on either side and tighten them. Tighten two bottom clamps on either side of those. Repeat in the same manner until you reach the ends. Try to avoid getting any glue on the cauls. You don’t want to glue your clamps to the stack. You can also take precautions by putting tape on the cauls.

{{< gallery  caption="Clamping the stack." >}}
{{< gallery-item src="images/Stack_Layup_Clamping.JPG" caption="Clamping a stack together." >}}
{{< gallery-item src="images/Stack_Layup_Done.JPG" caption="Stack clamped and drying." >}}
{{< /gallery >}}

I usually let a stack dry for three to four hours. I can make a few stacks per day.

The [Woodworking Resources]({{< ref "MonkeyWiki/Resources/Woodworking_Resources.md" >}}) page has a number of articles on proper clamping. These are all worth a read and will help you understand how much pressure you should use in order to get a good glue-up.

## Preparing the stack for slicing 
Once the stack is dry and out of the clamps, it needs to be prepared to be sliced. The first step is to remove all of the excess glue squeezed out during layup and clamping. This is easily done, as the polyurethane glue isn’t really structural. A [Hand Scraper]({{< ref "MonkeyWiki/Equipment/Small_tools/Hand_Scraper.md" >}}) makes short work of it. You don’t need remove all of it, just any glue that would prevent the stack from laying flat on each side.

{{< gallery  caption="Scrape off excess glue" >}}
{{< gallery-item src="images/Stack_Clean_Start.JPG" caption="A stack fresh out of the clamps with lots of excess glue squeezed out." >}}
{{< gallery-item src="images/Stack_Clean_Post_Scrape.JPG" caption="A stack with excess glue scraped off." >}}
{{< /gallery >}}

The wide sides of the stack will be uneven, since it’s almost impossible to find boards that are perfectly straight and to align them perfectly for clamping. I pick the side that looks the flattest and I run that over an 8” jointer until it is flat. I set the jointer to take off about 1/16th of an inch per pass. You want to remove the minimum amount of wood possible from now on. Pencil marks placed on the side being jointed beforehand make it easy to see which portions are smooth and where more work is needed. 

{{< gallery  caption="First side being jointed" >}}
{{< gallery-item src="images/Stack_Clean_First_Side_Jointed1.JPG" caption="A stack on the jointer, first side being process is down on the bed. Light passes make the side flat and remove the least material possible." >}}
{{< gallery-item src="images/Stack_Clean_First_Side_Jointed2.JPG" caption="A stack on the jointer, first side being process is down on the bed. Light passes make the side flat and remove the least material possible." >}}
{{< gallery-item src="images/Stack_Clean_First_Side_Jointed3.JPG" caption="A stack on the jointer, first side being process is down on the bed. Light passes make the side flat and remove the least material possible." >}}
{{< /gallery >}}

Once that face is flat, I turn the stack 90 degrees and flatten the bottom of the stack. To do this, I place the newly flat face against the fence of the jointer. Now we have one flat wide face, one flat adjacent base and those two surfaces are at 90 degrees to each other. 

{{< gallery  caption="Second side being jointed perpendicular to the first side" >}}
{{< gallery-item src="images/Stack_Clean_Second_Side_Jointed1.JPG" caption="A stack on the jointer, second side being processed is down on the bed. The first side is flat against the fence, ensuring that the two sides will be perpendicular." >}}
{{< gallery-item src="images/Stack_Clean_Second_Side_Jointed2.JPG" caption="A stack on the jointer, second side being processed is down on the bed. The first side is flat against the fence, ensuring that the two sides will be perpendicular." >}}
{{< /gallery >}}

Next, I flatten the other wide face by running the stack thru a planer with the jointed side down. This yields a stack which has two good sides, and one good base. Surfacing the fourth face is optional at this point and I usually skip it. Then, I take the stack over to my chop saw and trim the ragged ends square, if necessary. 

{{< gallery  caption="Third side being planed parallel to the first" >}}
{{< gallery-item src="images/Stack_Clean_Third_Side_Ready1.JPG" caption="A stack with two sides already processed on the jointer. The side that is up needs to be made flat and parallel to the other side using a planer. Pencil marks help us see how much work is left." >}}
{{< gallery-item src="images/Stack_Clean_Third_Side_Ready2.JPG" caption="A stack with two sides already processed on the jointer. The side that is up needs to be made flat and parallel to the other side using a planer. Pencil marks help us see how much work is left." >}}
{{< gallery-item src="images/Stack_Clean_Third_Side1.JPG" caption="A stack with two sides already processed on the jointer. The side that is up needs to be made flat and parallel to the other side using a planer. Pencil marks help us see how much work is left." >}}
{{< gallery-item src="images/Stack_Clean_Third_Side2.JPG" caption="A stack with two sides already processed on the jointer. The side that is up needs to be made flat and parallel to the other side using a planer. Pencil marks help us see how much work is left." >}}
{{< gallery-item src="images/Stack_Clean_Third_Side3.JPG" caption="A stack with two sides already processed on the jointer. The side that is up needs to be made flat and parallel to the other side using a planer. Pencil marks help us see how much work is left." >}}
{{< /gallery >}}

The stack is now ready for slicing.

{{< gallery  caption="Cleaned up stack ready for slicing" >}}
{{< gallery-item src="images/Stack_Clean_Complete1.JPG" caption="A stack cleaned up with two wide sides flat and parallel, and one base side flat and perpendicular to the others." >}}
{{< gallery-item src="images/Stack_Clean_Complete2.JPG" caption="A stack cleaned up with two wide sides flat and parallel, and one base side flat and perpendicular to the others." >}}
{{< /gallery >}}

Sometimes there are blemishes in the wood (knots, etc.) or uneven boards near the ends of a stack. That can be okay, as long as these blemishes are beyond the ends of any reasonable core you will build. Stacks are often longer than actual cores.

{{< gallery  caption="Blemishes on a stack that really don’t matter" >}}
{{< gallery-item src="images/Stack_Clean_Blemish1.JPG" caption="A blemish at the end of a stack may not matter if its beyond the end of any reasonable core you might build." >}}
{{< gallery-item src="images/Stack_Clean_Blemish2.JPG" caption="A blemish at the end of a stack may not matter if its beyond the end of any reasonable core you might build." >}}
{{< /gallery >}}

## See Also 
- [Core blank overview]({{< ref "MonkeyWiki/Construction/Core_blank_construction/Core_blank_overview.md" >}})
- [Wood selection, drying, and prep]({{< ref "MonkeyWiki/Materials/Wood_selection__drying__and_prep.md" >}})
- [Slicing a stack]({{< ref "MonkeyWiki/Construction/Core_blank_construction/Slicing_a_stack.md" >}})
- [Joining the halves of a core blank]({{< ref "MonkeyWiki/Construction/Core_blank_construction/Joining_the_halves_of_a_core_blank.md" >}})

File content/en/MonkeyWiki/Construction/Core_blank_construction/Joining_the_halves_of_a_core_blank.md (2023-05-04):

---
dateFromWiki: "2019-02-03T02:39:31Z"
title: "Joining the halves of a core blank"
gallery: true
aliases:
- /MonkeyWiki/Joining_the_halves_of_a_core_blank
- /MonkeyWiki/Joining_the_halves_of_a_core_blank/en
weight: 4
---
The final phase of creating a core blank is joining a pair of book-matched slices from a [Slicing a stack]({{< ref "MonkeyWiki/Construction/Core_blank_construction/Slicing_a_stack.md" >}}) to form a blank that is approximately 14” wide. (Of course, if you’re building skis then you don’t need to do this step, as one slice is plenty wide enough for a single ski!) The blank will be as long as the stack, which will at a minimum accommodate a board 180cm long. I create a small set of blanks each season that will yield a board up to 200cm long, but those are less frequently used. The thickness of the blank is determined by the thickness of the slices, with a goal of at least 0.400” thick to allow for the extra passes thru the planer required as a final core is formed.

The slices are joined with a little polyurethane glue along the center, and clamped with six or seven “4-way” clamps. These hold the slices perfectly aligned top-to-bottom while providing excellent pressure between the slices. You may notice some spacers in the pictures between the core and the clamps. These are to make up for the fact that most core blanks are thinner than the clamps are designed to accommodate. It’s a problem easily solved with a few strips of 1/4" hardboard waxed or taped a bit to prevent the glue from sticking.

I find that sometimes the edges of the slices aren’t perfectly straight because, after all, it’s difficult to get the top and bottom of such a heavy, long stack perfectly flat. I usually solve this by clamping my slices together and running the edges to be joined across the joiner in a few light passes. You could also rip them straight with a tablesaw and a jig.

When the blank comes out of the clamps it has a nice bead of dried glue along both sides, and some smear from the clamps. This is simply scraped off with a hand-scraper. The foamed poly glue isn’t very strong and comes off easily, leaving a core blank that is ready to finally become a core.
{{< gallery  caption="Joining halves of a core blank" >}}
{{< gallery-item src="images/CoreBlank_SliceJoin1.JPG" caption="Halves of a core blank coming together." >}}
{{< gallery-item src="images/CoreBlank_SliceJoin2.JPG" caption="Joining halves of a core blank. You can clearly see the glue squeezeout and the spacers for the clamps." >}}
{{< gallery-item src="images/CoreBlank_SliceJoin3.JPG" caption="A core blank fresh out of the clamps. The excess glue needs to be scraped off using the hand-held scraper visible in the distance." >}}
{{< /gallery >}}

## See Also 
- [Core blank overview]({{< ref "MonkeyWiki/Construction/Core_blank_construction/Core_blank_overview.md" >}})
- [Wood selection, drying, and prep]({{< ref "MonkeyWiki/Materials/Wood_selection__drying__and_prep.md" >}})
- [Building a stack]({{< ref "MonkeyWiki/Construction/Core_blank_construction/Building_a_stack.md" >}})
- [Slicing a stack]({{< ref "MonkeyWiki/Construction/Core_blank_construction/Slicing_a_stack.md" >}})
- [Four-way Clamps]({{< ref "MonkeyWiki/Equipment/Small_tools/Four-way_Clamps.md" >}})

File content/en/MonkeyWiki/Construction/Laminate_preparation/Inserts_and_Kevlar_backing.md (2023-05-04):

---
dateFromWiki: "2019-03-24T20:55:05Z"
title: "Inserts and Kevlar backing"
gallery: true
aliases:
- /MonkeyWiki/Inserts_and_Kevlar_backing
- /MonkeyWiki/Inserts_and_Kevlar_backing/en
weight: 2
---
# Raw Notes
This is a temporary page containing raw, unedited notes on this subject. This page and the information here is incomplete, and may be inaccurate. 

- Kevlar, biax, woven, measured at 0.004", used for inserts, not sure of original width, but quite wide. 1.70 oz./yd.² (58 g/m²) Warp 34 Kevlar 49 195 Denier X Fill 34 Kevlar 49 195 Denier, Plain Weave, 3.0 mils (.08 mm) Thickness.
- Need info on the inserts: type, cap, source, heights, weights, typical number/spacing.
- Holes are cut on the CNC machine with programs from MonkeyCAM. The fit is snug, but does not require a hammer to get them in.
- Kevlar is pre-cut, slits pre-cut before layup. Wet the kevlar with epoxy during layup, place, and push inserts thru at that time. I keep a small tac hammer nearby just in case any insert is difficult to seat.
- {{< img src="images/Fibers3.JPG" >}}A patch of Kevlar which the inserts are pushed through provides stronger insert retention, and greatly reduces “binding suck”: that phenomena where the base underneath the bindings tends to suck in to the core when the bindings are tightened.
- The standard snowboard binding pattern is 4cm x 4cm, thus the "4x4" you typically see. You can add as many sets as you'd like, but recognize that you're drilling more and more holes in your core, and thru your top layer of glass. quite typical is 4 rows 4cm apart.
  - The "machine gun" pattern is staggering your rows by 2cm, so you have finer options for stance width at the expense of more holes and inserts.
  - There is a standard splitboard pattern developed by Voile. It can be found directly from them here: http://www.voile.com/voile_splitboard_hole_pattern_specs.pdf
    - I have archived this here: [Voile_splitboard_hole_pattern_specs.pdf](/files/Voile_splitboard_hole_pattern_specs.pdf)

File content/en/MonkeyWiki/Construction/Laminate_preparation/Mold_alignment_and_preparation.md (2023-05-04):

---
dateFromWiki: "2019-03-23T19:27:33Z"
title: "Mold alignment and preparation"
aliases:
- /MonkeyWiki/Mold_alignment_and_preparation
- /MonkeyWiki/Mold_alignment_and_preparation/en
weight: 4
---
# Raw Notes
This is a temporary page containing raw, unedited notes on this subject. This page and the information here is incomplete, and may be inaccurate. 

Marking: This is a critical job, with marks placed on multiple pieces.

- The bottom cassette piece, which for me is a single piece of aluminum. 
  - A mark across the width of it for the center of the effective edge. This is used to align the cassette to the mold when it all goes in the press. This is also used to align both layers of glass and the top sheet during layup. It is also used to align the base before adhering it to the cassette with Super77 spray glue.
  - Marks for the center, lengthwise, at each end of where the board will be. Used to align the base, glass, and top sheet.
  - These marks must be visible outside the bounds of all materials that go in the board.
- The core.
  - Centerlines on the nose and tail, and the center of the effective edge. You want these on the edges of the core so you can align the core with the base easily.
- Both layers of glass
  - Centerlines on the ends, and marks for the middle at the effective edge. Makes it very easy to get your glass placed straight the first time during layup.
- The topsheet.
  - Centerlines on the ends, and marks for the middle at the effective edge. With a little precision laying out your lines you can a) place your topsheet accurately quickly during layup, and b) can get it dead center. This is critical for any graphics or designs which have a center line, as it will be obvious if you're off when you drill out the inserts.

Mold prep

- I wax both the top and bottom mold skins with Johnsons paste wax. I buff the top skin, but not the bottom skin.
- I leave a strip of unwaxed area on the bottom skin about 4-5" wide and about the length of the effective edge. This is where I add Super77 spray glue to adhere the base.
- I reuse mold skins, so the first step is to remove any old epoxy. There is always some left around the edges of where the board was. Most of it just pops off, but some may need to be scraped with something stiff and hard, or maybe sanded. Try not to score the skin, you want it smooth.

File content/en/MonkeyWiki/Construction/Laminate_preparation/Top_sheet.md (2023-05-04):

---
dateFromWiki: "2019-03-31T18:39:53Z"
title: "Top sheet"
gallery: true
aliases:
- /MonkeyWiki/Top_sheet
- /MonkeyWiki/Top_sheet/en
weight: 3
---
# Raw Notes
This is a temporary page containing raw, unedited notes on this subject. This page and the information here is incomplete, and may be inaccurate. 

- I use wood veneer for my top sheets, wetted out both sides with epoxy during layup.
- Standard "raw" wood veneer, i.e., not paper-backed. Typical thickness is around 0.026" or so. 
- I cut and join different woods, usually with a simple stripe down the center. It's easy to do and looks nice, and lets you combine a few different woods together.
- Veneer is joined with standard veneer tape on the underside. I wet this with epoxy carefully during layup and it stays inside the board. It's so thin it just doesn't matter.
- I've used some curved forms to cut long arcs in the veneer, and joined those. This was a pain in the ass though, fair warning. Cutting and joining thin veneer what doesn't lay flat well is quite hard.
- Try to use the flattest veneer you can find if you're joining it. It can be difficult to end up with a straight joint with very wavy, warped veneer.
- A long time ago I used pre-printed top sheets from Creative Edge Graphics in WA. These were PBT.
- I've also used clear top sheets. Some Duravision IIRC, and something else I need to look up. These are nice because you can see your top layer of fibers, core alignment, nose/tail spacer alignment, etc. You can also see if there are any dry spots due to poor wet out, voids, air bubbles, etc.
- Mark center lines on the edges of the topsheet so you can get it straight during layup. These marks match centering marks I have on the cassette. 
- Note how veneer colors change with pressing, and teach how I made my sample cards.
  - Old FB post: When I use wood veneer for my snowboard top sheets it always darkens. It's the epoxy and heat used during pressing. Since I got some new veneer I decided to make a bunch of test cards so I could see exactly what I'm working with. 10 different kinds of wood pressed with epoxy and fiberglass as if done for a snowboard, with white card stock glued to the backs for labels.

{{< gallery  caption="Misc Veneer Pics" >}}
{{< gallery-item src="images/Board_2018.jpg" caption="Completed board from Winter 2018. Wood veneer topsheet with highly figured Bubinga, English Sycamore, and Ebony. 164cm." >}}
{{< gallery-item src="images/Veneer_top_1.jpg" caption="Veneer topsheet ready to go, bottom-up." >}}
{{< gallery-item src="images/Veneer_Cards_1.jpg" caption="Self-made veneer sample cards, using my epoxy and heated press to ensure I see how they will color when pressing a board." >}}
{{< gallery-item src="images/Veneer_Cards_2.jpg" caption="Veneer cards backed with white notecard stock, held on with Super77 spray glue." >}}
{{< gallery-item src="images/Veneer_Cards_3.jpg" caption="Example showing veneer cards against the raw veneer." >}}
{{< gallery-item src="images/Veneer_Top_2.jpg" caption="Veneer top sheets for skis." >}}
{{< gallery-item src="images/Veneer_Top_3.jpg" caption="Form for cutting curved veneer." >}}
{{< gallery-item src="images/Veneer_Top_4.jpg" caption="Raw veneer for top sheets." >}}
{{< gallery-item src="images/Veneer_Top_5.jpg" caption="Three veneers selected to become a top sheet." >}}

{{< gallery-item src="images/Veneer_Top_11.jpg" caption="Veneer being cut with a long straight edge of aluminum extrusion and a classic veneer saw." >}}
{{< gallery-item src="images/Veneer_Top_10.jpg" caption="Veneer cut and ready to be joined." >}}
{{< gallery-item src="images/Veneer_Top_9.jpg" caption="Veneer temporarily taped on the top side with blue painters tape." >}}
{{< gallery-item src="images/Veneer_Top_8.jpg" caption="Veneer being joined with classic paper tape." >}}
{{< gallery-item src="images/Veneer_Top_7.jpg" caption="Veneer top sheet, joined and ready to go, bottom view." >}}
{{< gallery-item src="images/Veneer_Top_6.jpg" caption="Top of veneer top sheet, joined and ready to go." >}}
{{< /gallery >}}

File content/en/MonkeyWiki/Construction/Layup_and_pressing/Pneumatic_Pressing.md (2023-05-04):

---
dateFromWiki: "2019-03-23T20:06:27Z"
title: "Pneumatic Pressing"
aliases:
- /MonkeyWiki/Pneumatic_Pressing
- /MonkeyWiki/Pneumatic_Pressing/en
weight: 3
---
# Raw Notes
This is a temporary page containing raw, unedited notes on this subject. This page and the information here is incomplete, and may be inaccurate. 

- Press prep, precheck, etc.
- Compressor full and ready
- Mold configuration and alignment. This may warrant its own page.
- Thermocouple placement, testing of heat system, reset heat system.
- Talc for the blankets
- Setup for easy insertion
- Alignment during insertion.
- Initial pressure and verification.
- Full pressure. What pressure and why. Why more isn't better.
- Heat on and ramp, soak, ramp down, total time of each.
- Maintaining even heat top to bottom during ramp up.
- Catching resin overflow if you used too much.
- When to remove it. I remove it after about 30min after the soak time is over, because I'm impatient. Some people pull it out right away with no cooling. Some people leave it in overnight to completely cool before removing it. So what's right?

# Old notes on pressing, also raw

Pressing process

Overview of what the press is, what it is used for, how to operate it, etc. Essentially, the process of using the press to build a board: heating evenly, pressure, time, cooling, etc.

I press the average width board at right around 50psi. This presses the laminate completely into the mold, and results in good squeeze out without removing too much resin. I compute the fiber fraction of every board I build and carefully track this to ensure I’m getting the ratio of glass to resin we’re after. For especially narrow boards I drop the pressure proportionally. Pneumatic presses are capable of amazing pressures, but too much pressure is just as bad as too little. Too much pressure results in a dry laminate that is weak and prone to delamination.

The press heats both the top and bottom of the laminate to 175F with two 2,083 watt heat blankets that provide direct, even, controlled heat to the board to properly cure the epoxy. The combination of pressure and heat results in a very flat board on top and bottom, appropriate squeeze out of excess epoxy, and perfectly consolidated fiberglass layers.

The heater control has one PID controller with ramp/soak for controlling the heat of both blankets. Temperature is measured below the center of the board. It also has a second temperature sensor to monitor the heat transfer in other locations. It’s helpful to see the lag between the heat on the bottom and on the top of the board during pressing.

I ramp the heat up from room temperature to 175F slowly, then hold the heat steady for a one hour cure under pressure. The laminate is cooled slowly down to about 145F, over the course of 30 min, before being removed from the mold. The laminate is the allowed to rest for two days before first flex to allow the epoxy to continue to cure undisturbed.

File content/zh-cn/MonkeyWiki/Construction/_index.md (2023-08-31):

---
dateFromWiki: "2019-04-17T08:53:08Z"
title: "建造概况"
aliases:
- /MonkeyWiki/Construction_Overview/zh-cn
translatedDate: "2019-04-17T08:53:08Z"
translator: "X z"
translatorPage: "/zh-cn/MonkeyWiki/X_z"
weight: 1
bookCollapseSection: true
---
以下文章介绍了制造滑雪板的过程，假设你拥有可用的[设备概述]({{< ref "MonkeyWiki/Equipment" >}})和[材料概述]({{< ref "MonkeyWiki/Materials" >}})。 

- 准备
  - [施工清单]({{< ref "MonkeyWiki/Construction/Preparation/Construction_Checklist.md" >}})
- 空白板制造
  - [芯坯概述]({{< ref "MonkeyWiki/Construction/Core_blank_construction/Core_blank_overview.md" >}})
  - [木材选择，干燥和准备]({{< ref "MonkeyWiki/Materials/Wood_selection__drying__and_prep.md" >}})
  - [制作芯坯]({{< ref "MonkeyWiki/Construction/Core_blank_construction/Building_a_stack.md" >}})
  - [切割芯坯]({{< ref "MonkeyWiki/Construction/Core_blank_construction/Slicing_a_stack.md" >}})
  - [拼接另外一半空白板芯]({{< ref "MonkeyWiki/Construction/Core_blank_construction/Joining_the_halves_of_a_core_blank.md" >}})
- 板芯制造
  - [白蜡木桁条和边墙]({{< ref "MonkeyWiki/Construction/Core_construction/Ash_edge_stringer_and_sidewalls.md" >}})
  - [嵌体后清理，最后空白板定型]({{< ref "MonkeyWiki/Construction/Core_construction/Cleanup_after_inlay__and_final_blank_sizing.md" >}})
  - [数控板芯切割]({{< ref "MonkeyWiki/Construction/Core_construction/CNC_Core_Cutting.md" >}})
  - [最后的清理与边墙准备]({{< ref path="MonkeyWiki/Construction/Core_construction/Final_cleanup_and_sidewall_preparation.md" lang="en" >}})
- 层压板准备
  - [板底, 边刃, 板头和板尾垫片]({{< ref "MonkeyWiki/Construction/Laminate_preparation/Bases__edges__and_nose_tail_spacers.md" >}})
  - [嵌件和凯夫拉背衬]({{< ref path="MonkeyWiki/Construction/Laminate_preparation/Inserts_and_Kevlar_backing.md" lang="en" >}})
  - [顶片]({{< ref path="MonkeyWiki/Construction/Laminate_preparation/Top_sheet.md" lang="en" >}})
  - [模具对齐和准备]({{< ref path="MonkeyWiki/Construction/Laminate_preparation/Mold_alignment_and_preparation.md" lang="en" >}})
- 铺层和压制
  - [混合环氧树脂]({{< ref path="MonkeyWiki/Construction/Layup_and_pressing/Mixing_epoxy.md" lang="en" >}})
  - [湿法铺层]({{< ref path="MonkeyWiki/Construction/Layup_and_pressing/Wet_layup.md" lang="en" >}})
  - [气动压制]({{< ref path="MonkeyWiki/Construction/Layup_and_pressing/Pneumatic_Pressing.md" lang="en" >}})
- 收尾
  - [清理和精加工概述]({{< ref "MonkeyWiki/Construction/Finishing/Overview_of_cleanup_and_finishing.md" >}})
  - [精加工木饰面板]({{< ref "MonkeyWiki/Construction/Finishing/Finishing_a_wood_veneer_top_sheet.md" >}})
  - [简单的丝网印刷]({{< ref path="MonkeyWiki/Construction/Finishing/Simple_screen_printing.md" lang="en" >}})
  - [调整和打蜡]({{< ref path="MonkeyWiki/Construction/Finishing/Tuning_and_waxing.md" lang="en" >}})
- 测量和测试
  - [重量和纤维分数]({{< ref "MonkeyWiki/Construction/Measurement_and_testing/Weights_and_fiber_fraction.md" >}})
- [真空压制]({{< ref path="MonkeyWiki/Construction/Vacuum_Pressing.md" lang="en" >}})

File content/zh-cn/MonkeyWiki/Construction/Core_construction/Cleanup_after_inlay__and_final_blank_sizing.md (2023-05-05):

---
dateFromWiki: "2019-04-08T22:34:16Z"
title: "嵌体后清理，最后空白板定型"
gallery: true
aliases:
- /MonkeyWiki/Cleanup_after_inlay,_and_final_blank_sizing/zh-cn
translatedDate: "2019-04-08T22:34:16Z"
translator: "X z"
translatorPage: "/zh-cn/MonkeyWiki/X_z"
---
胶水干燥后，空白板必须清理干净。必须刮去多余的胶水，并且必须使用刨刀在两侧完全平滑坯料。为了从压刨中获得良好的第一次通过，白蜡木条和PTEX上的任何高点都需要用短刨手动刨除掉。一旦空白板在压刨中完成，底座就完成了。没有进一步平滑，它必须是完全平坦的。我非常注意保持压刨良好的工作状态，并确保底座上的最终通道很轻。这给了我高质量的表面。

我喜欢我们的空白板看待这个阶段的方式。它们非常光滑，沿着有效边刃的PTEX和2cm白蜡木条是非常光滑的。通常在这一点上，我很遗憾这些漂亮的板芯在最终产品中会变得模糊不清。

在此步骤之后，坯料仍然比板的最终厚度厚。厚度曲线将由CNC机器在稍后的步骤中应用。

我使用的是JET 15英寸压刨，宽度足以容纳滑雪板芯空白的宽度。如果你正在制作滑雪双板，你可以使用更小的压刨。

这是一个简短的视频，显示了从空白板到最终板芯的每个步骤，包括镶嵌，清理和最终空白大小。

{{< youtube pQZlsaCv4dY >}}

{{< gallery  caption="清除边墙嵌体和最终芯空白厚度" >}}
{{< gallery-item src="images/CoreBlank_InlayCleanup4.JPG" caption="Core blank out of the clamps with lots of expanded polyurethane glue. It is scraped off, and a block plane is used to take down any high spots on the cleanest side to prepare for the mechanical planer." >}}
{{< gallery-item src="images/CoreBlank_InlayCleanup5.JPG" caption="Core blank out of the clamps with lots of expanded polyurethane glue. It is scraped off, and a block plane is used to take down any high spots on the cleanest side to prepare for the mechanical planer." >}}
{{< gallery-item src="images/CoreBlank_InlayCleanup1.JPG" caption="Core blank with PTEX and ash inlay being planed." >}}
{{< gallery-item src="images/CoreBlank_InlayCleanup2.JPG" caption="Core blank with PTEX and ash inlay being planed." >}}
{{< gallery-item src="images/CoreBlank_InlayCleanup3.JPG" caption="Core blank with PTEX and ash inlay being planed." >}}
{{< gallery-item src="images/CoreBlank_InlayCleanup6.JPG" caption="Blank ready for final shaping on the CNC machine." >}}
{{< gallery-item src="images/CoreBlank_InlayCleanup7.JPG" caption="Detail of the PTEX and ash inlay." >}}
{{< gallery-item src="images/CoreBlank_InlayCleanup8.JPG" caption="Detail of the PTEX and ash inlay." >}}
{{< /gallery >}}

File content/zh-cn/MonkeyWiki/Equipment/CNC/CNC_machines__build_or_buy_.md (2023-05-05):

---
dateFromWiki: "2019-05-04T10:50:46Z"
title: "数控雕刻机: 自己造还是买?"
aliases:
- /MonkeyWiki/CNC_machines:_build_or_buy_/zh-cn
- /MonkeyWiki/CNC_machines:_build_or_buy/zh-cn
- /MonkeyWiki/CNC_machines:_build_or_buy?/zh-cn
translatedDate: "2019-05-04T10:50:46Z"
translator: "X z"
translatorPage: "/zh-cn/MonkeyWiki/X_z"
weight: 3
---
人们经常问我是否应该建造自己的CNC机器，就像我建造的[CNC 雕刻机]({{< ref "MonkeyWiki/Equipment/CNC/CNC_Router.md" >}})或只买一台。我不一定要劝阻任何人，但这实际上取决于你想要花费多少时间和精力来建造机器，而不是你想花多少时间来使用机器。据推测，毕竟你想要一台CNC机器来帮助你完成一些有趣的任务！

建造自己的数控机床很有趣，而且你能学到了很多东西。但是你应该睁大眼睛看看你正在进行的事情。
 
首先，我假设你要构建一个大型工作台CNC雕刻机，与目前市场上合理的低端CNC雕刻机相媲美，如基本型号[Shopbot](http://www.shopbottools.com/)。但是，还有很多其他选择，例如具有较小切削区域的台式机，或者由MDF和塑料制成的精度较低的机器，这些机器非常适合许多项目，并且是以低成本学习CNC的好方法。我没有任何这些替代品的经验，所以我将自己限制在精密CNC雕刻机上。
 
我的目标是制造一台精确的机器，可重复定位在+/-0.005英寸之内，并且经过多年的使用和合理的维护。它应该足够坚硬，以合理的速度切割半英寸的MDF或杨木，例如100IPM，保持2-3hp的雕刻机，并旋转直径达1.5英寸的钻头。你应该首先为自己建立类似的目标：确定你需要的精度，要切割的材料以及切割速度。使用商用数控机床的规格作为指导。
 
建造一台好的数控机床并不比从Shopbot这样的全套装备买一台好机器便宜得多。我在2003年制造我的机器花费了不到6,000美元，而当时我可以从Shopbot购买一台机器，这台机器准确，速度稍快，价格不到8,000美元。坦率地说，价格的差异是合理的：Shopbot有一个更坚固的框架，更大的电机等。我还节省了合理的金钱从eBay购买一些零件。进入它的组件并不便宜，特别是步进电机，线性滑轨和框架材料。如果你决定自己构建一个区域，这三个区域根本不应该吝啬。然而这些是我经常看到人们试图节约的三个，这只会让他们后来感到难过。
 
构建精确，刚性的数控机床需要大量的时间和精密的金属加工。在某些时候，你需要至少使用手动膝盖铣刀的人帮助压平各种安装板，并在关键区域钻出非常精确的孔。你尝试制造机器的精度越高，加工零件时的精度就越高。当你拿到它们时，许多材料实际上并不是平的，即使肉眼看起来它们可能看起来很平坦。优质的线性滑轨必须安装在非常平坦的表面上，否则当螺栓拧紧时它们会弯曲。这将导致轴承结合，没有任何动作。精密加工的一些背景对于构建良好的CNC雕刻机至关重要。
 
你还需要一些基础电子学的背景知识。这些机器可以在所有电机，驱动器和控制器之间以220v的速度轻松吸取30A。你应该熟悉高压交流和低压直流电。
 
如果你决定建立自己的机器，我强烈推荐两件事：
1. 在当地社区或技术学院寻找精密加工课程。我在[华盛顿湖技术学院](http://www.lwtc.edu/)的晚上参加了两门精密加工课程，非常棒。没有他们，我肯定无法建立我的第一台机器。
1. [数控空间](http://www.cnczone.com/)。这是一个由DIY数控制造商组成的梦幻社区，拥有材料和部件资源，设计和施工建议等。

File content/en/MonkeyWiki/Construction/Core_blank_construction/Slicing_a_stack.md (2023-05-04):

---
dateFromWiki: "2019-02-03T02:33:16Z"
title: "Slicing a stack"
gallery: true
aliases:
- /MonkeyWiki/Slicing_a_stack
- /MonkeyWiki/Slicing_a_stack/en
weight: 3
---
I set my bandsaw up to resaw the stack into slices about 0.5” thick. The stack is less than 2.5” thick from the previous cleanup step, and each pass thru the saw will waste a bit of material as well (the kerf of the blade.) In order to get four slices each 0.5” thick, then, it is critical that the bandsaw is setup well and that you are reasonably practiced at resawing. Don’t practice on one of your precious stacks… use some cheap scrap wood, or even buy a larger beam of wood to practice on. Each side of a slice will eventually have to be perfectly flat, and any wobbles while resawing the stack means lost thickness later. The thicker you can leave each slice, the more freedom you’ll have in your processes later.

There are some excellent articles on resawing linked on the [Woodworking Resources]({{< ref "MonkeyWiki/Resources/Woodworking_Resources.md" >}}) page.

I set an extra high fence on my bandsaw and test it with scrap wood to ensure I’m getting the cut I want. I use a square to ensure the fence is perpendicular to the table. I use some adjustable wood “fingers” ([Feather Board]({{< ref "MonkeyWiki/Equipment/Small_tools/Feather_Board.md" >}})) to help apply pressure and keep the stack tight against the fence. Outfeed rollers are required to support the stack since it is quite heavy.

{{< gallery  caption="Bandsaw setup" >}}
{{< gallery-item src="images/Bandsaw_Setup1.JPG" caption="Setting up the bandsaw fence using a good square is important to getting good slices." >}}
{{< gallery-item src="images/Bandsaw_Setup2.JPG" caption="A quick test with a piece of scrap wood helps dial in the thickness." >}}
{{< gallery-item src="images/Fingers.JPG" caption="A feather board on the bandsaw helps keep the work tightly against the fence." >}}
{{< gallery-item src="images/Stack_Slicing_Ready1.JPG" caption="Setting up the bandsaw to take slices off of a stack. Here you can see the infeed and outfeed roller arrangement." >}}
{{< gallery-item src="images/Stack_Slicing_Ready2.JPG" caption="Setting up the bandsaw to take slices off of a stack. Here you can see the infeed and outfeed roller arrangement." >}}
{{< gallery-item src="images/Stack_Slicing_Ready3.JPG" caption="Setting up the bandsaw to take slices off of a stack. Here you can see the infeed and outfeed roller arrangement." >}}
{{< /gallery >}}

I cut the first slice. That slice has one good face from the jointer earlier, and one rough face from the bandsaw. It is labeled #1, and I’ll number the next three as they come off the bandsaw. If I were to slice #2 now there would be two problems: first, the rough surface against the fence might transfer any mistake on the first slice to the second, and second slice #2 would have two rough surfaces. Because the slice is thin and long it is difficult to work on the jointer, and thus it would be very difficult to give this slice two good surfaces later. So, after the first slice I take the stack back to the planer and cleanup the newly rough surface. 

{{< gallery  caption="First slice and stack cleanup" >}}
{{< gallery-item src="images/Stack_Slicing_First_Slice.JPG" caption="The first slice removed from the stack." >}}
{{< gallery-item src="images/Stack_Slicing_Cleanup_After_First.JPG" caption="The stack after the first slice is removed. It is marked with pencil, especially in places where there was a bit of a wobble during cutting, to help us see how much material needs to be removed. It will be minimal." >}}
{{< /gallery >}}

I return the stack to the bandsaw for slice #2, ensuring I pass the stack thru the saw in the same orientation as slice #1. Cleanup on the planer again.

{{< gallery  caption="Second slice and stack cleanup" >}}
{{< gallery-item src="images/Stack_Slicing_Second_Slice.JPG" caption="The second slice removed from the stack." >}}
{{< gallery-item src="images/Stack_Slicing_Cleanup_After_Second.JPG" caption="The stack after the second slice is removed. It is marked with pencil and already had one pass through the planer. You can see a bit of pencil left in the upper left of it, indicating a tiny bit more needs to come off." >}}
{{< /gallery >}}

Rinse and repeat for slice #3 and the left over is slice #4. Note that slice #4 has one good surface because we ensured both wide faces of the stack had good surfaces when preparing the stack.

{{< gallery  caption="Third and fourth slices, and all four off the bandsaw" >}}
{{< gallery-item src="images/Stack_Slicing_Third_and_Fourth.JPG" caption="The third slice removed from the stack, leaving the fourth." >}}
{{< gallery-item src="images/Stack_Slicing_Slices.JPG" caption="The stack completely sliced up, with the extra off to the right. This was an especially good production… usually I have nothing left over!" >}}
{{< /gallery >}}

I now have four slices, each with one good surface. The slices will be treated in pairs from now on: #1 and #2 together, and #3 with #4.

## Finishing the slices 
Now the slices need to get their rough sides cleaned up. Two slices will become one core blank, so each pair of slices need to be the same thickness. The pairs can be different thicknesses, though, and I recommend doing a single pair at a time to ensure you get the maximum thickness you can out of each set. Using the planer, pass the thicker of slice #1 or slice #2 thru until the planer just starts hitting the surface. Now, adjust the planer down in small increments and pass each slice thru, one after the other, until both slices are perfect. Always keep the original surface from the jointer facing down, and stop as soon as both slices are flat. I mark the wheel on my planer with a bit of tape, and on my planer a “small increment” is roughly 1/8th of a turn.

{{< gallery  caption="Cleaning up a pair of slices" >}}
{{< gallery-item src="images/Stack_Slicing_Pair_Cleanup1.JPG" caption="A pair of slices with one good side each facing down, and one side fresh from the bandsaw facing up. Marked with pencil to help see where more work is needed." >}}
{{< gallery-item src="images/Stack_Slicing_Pair_Cleanup2.JPG" caption="A pair of slices. The one on the right has been passed thru the planer once. The one on the left is next, then we’ll adjust the planer in tiny increments until both are perfect." >}}
{{< gallery-item src="images/Stack_Slicing_Pair_Cleanup3.JPG" caption="A pair of slices, with one passing thru the planer." >}}
{{< /gallery >}}

Complete slices have two perfectly flat and parallel faces, and one edge that is also perfectly flat (it was the base of the stack.) Flipping one of the slices over bookmatches them: the center strip is from the same original board, the next out is from the same original board, and so on. This will yield a core with wood that has fairly symmetrical properties from edge to edge. It won’t be perfect, since there is always variance even within a single board, but it’s as close as we can practically get!

{{< gallery  caption="Slices complete and bookmatching" >}}
{{< gallery-item src="images/Stack_Slicing_Pair_Done1.JPG" caption="A pair of slices complete. Both sides are perfectly smooth and parallel." >}}
{{< gallery-item src="images/Stack_Slicing_Pair_Done2.JPG" caption="A pair of slices complete, with one flipped over to show how they will be assembled into a core later. This is called “bookmatching” the slices. Imagine the pages of a book laid open; the wood in the center is from the same original board." >}}
{{< /gallery >}}

If you find that there is a poor spot near the edge of one slice, or at the end of a slice, don’t go crazy trying to get rid of it. Look at how the slices will be assembled into a final blank and determine if a bad spot would likely be a problem given the final shape of a snowboard. If not, then leave it rough in that spot in favor of maintaining the overall thickness of the slices.

Finally, always label your slices clearly with their thickness and something to indicate that they are a pair. I usually use the date of production, and a letter for each pair as shown in the picture below. These slices came out quite thick for snowboards and will provide plenty of wiggle room as sidewalls are inlaid later on.

{{< gallery  caption="All slices from one stack complete" >}}
{{< gallery-item src="images/Stack_Slicing_Labeling.JPG" caption="Four slices paired and labeled, indicating the date of production, the thickness of the blank, and a letter to ensure paired slices stay together." >}}
{{< gallery-item src="images/Stack_Slicing_Done.JPG" caption="Four good slices all done and ready to be joined into final core blanks." >}}
{{< /gallery >}}

## See Also 
- [Core blank overview]({{< ref "MonkeyWiki/Construction/Core_blank_construction/Core_blank_overview.md" >}})
- [Wood selection, drying, and prep]({{< ref "MonkeyWiki/Materials/Wood_selection__drying__and_prep.md" >}})
- [Building a stack]({{< ref "MonkeyWiki/Construction/Core_blank_construction/Building_a_stack.md" >}})
- [Joining the halves of a core blank]({{< ref "MonkeyWiki/Construction/Core_blank_construction/Joining_the_halves_of_a_core_blank.md" >}})

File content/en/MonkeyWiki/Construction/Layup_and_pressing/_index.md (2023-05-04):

---
weight: 5
bookCollapseSection: true
---

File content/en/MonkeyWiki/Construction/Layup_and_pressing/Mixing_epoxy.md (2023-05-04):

---
dateFromWiki: "2019-03-23T19:49:47Z"
title: "Mixing epoxy"
aliases:
- /MonkeyWiki/Mixing_epoxy
- /MonkeyWiki/Mixing_epoxy/en
weight: 1
---
# Raw Notes
This is a temporary page containing raw, unedited notes on this subject. This page and the information here is incomplete, and may be inaccurate. 

- Add in some of the good generic info on what epoxy is, how it cures, thin film vs 100g in a pot, splitting it and spreading it over the glass first, splitting the rest, etc.
- Tinting the hardener to learn if you're mixing well. 
- Get a video of the entire mixing process.
- Get everything ready beforehand. See my checklist. Scale, cups labeled with how much each of resin and hardener you need in each, stir sticks, paper towels, extra gloves, hammer to close the cans, tool to open the cans, etc.
- Mix by weight whenever possible, but see the epoxy specs to be sure. I use a scale accurate to 1g. I've read at least one epoxy spec sheet that said to mix by weight within 5% of goal. I go for within 1g, because why not.
- Two cup mixing method:
  - Measure your hardener into one cup, and your resin into another. 
  - Pour the hardener into the resin, and get as much out as you can quickly. 
  - Stir well for 1 min.
  - Pour the entire mix back into the hardener cup. Scrape the resin cup well, ensuring you get all resin out of the bottom edges.
  - Stir well for 1 min, being sure to scrape the sides and bottom edges well at least once.
  - Profit.
- After mixing, I pour half of my mix into a 3rd, clean cup, usually a plastic party drink cup. This divides the mass of the mix and helps keep a control on heat and pot life.
- I then pour the remaining half of the mix, still in the hardener cup, onto both glass layers. I then pour half of what's in the party cup back into the hardener cup, so I end up with 1/4 of my mix in each cup ready for the rest of the layup process. I then go back and spread the resin I poured on the glass well, and go on from there. As I layup, I take mixed epoxy from each cup alternatively until it's all gone.
- Pot life: this is typically specified as the time it takes for 100g of mixed epoxy to set at 77F. Increase the temp or the volume, and your pot life shortens. 
- Thin film set time: this is typically specified as the time it takes for a thin film of spread epoxy to set at 77F, and is usually much, much longer than the pot life. You can relax once you've spread all of your epoxy into a thin film.
- Do not artificially heat your epoxy to make it flow better, or easier to mix, or whatever. Keep it at room temp and use it from there, ideally around 70F. Only apply heat once it's in the press.
- Do not artificially cool your epoxy to try to get a longer pot life. It will just make it too thick, hard to mix, and hard to wet out your glass. You'll spend more time trying to do these things and lose any advantage you might have tried to get.
- **Never let a large mass of epoxy (> 100g) cure in a cup unattended. Depending on your epoxy, this could generate a great deal of heat, melt the cup, smoke, or even burn. Smoke from epoxy is toxic and you should get it outside ASAP, and get yourself to fresh air. Do not breath it.**
- Always test new epoxy. I once got a batch from a reputable manufacturer which was bad. When mixed it turned white, took forever to cure, bubbled, and was brittle when cured. They replaced it, of course, but I would have been sad if I'd found out during a layup.
- Mix a 100g test sample, apply it to a few "coupons" of fiberglass, and press them with proper heat. Ensure the coupons demonstrate the cured properties you expect: flexible, clear, strong, etc. Make sure a portion of it cures at room temperature as you would expect. Label the cans of each batch, and label the coupons, and keep them.
- Use epoxy specifically formulated for snowboards and skis, not a brittle epoxy designed for boats.
- Explain using pigment to learn to mix well. A very little bit of pigment mixed with the hardener only will show swirls and voids where you have unmixed resin.
- How much to mix: see the section on fiber fractions and weights. 
- Epoxy and heated cures. Post cures. Heat is always better.
- Get the interview with Roy post back on Skibuilders, and link to it from here. Heck, maybe copy it here if Kam is cool with that. Super-valuable and should never be lost. I have it in a forum full backup in my own archive just in case.

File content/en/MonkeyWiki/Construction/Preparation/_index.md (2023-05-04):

---
weight: 1
bookCollapseSection: true
---

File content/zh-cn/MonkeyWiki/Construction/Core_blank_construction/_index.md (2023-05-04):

---
title: "空白板制造"
weight: 2
bookCollapseSection: true
---

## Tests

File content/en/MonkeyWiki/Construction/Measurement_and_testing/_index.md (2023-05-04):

---
weight: 7
bookCollapseSection: true
---

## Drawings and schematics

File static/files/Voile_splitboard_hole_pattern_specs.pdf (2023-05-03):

## Voilé Splitboard Hole Pattern Specs

Dimensions in inches.

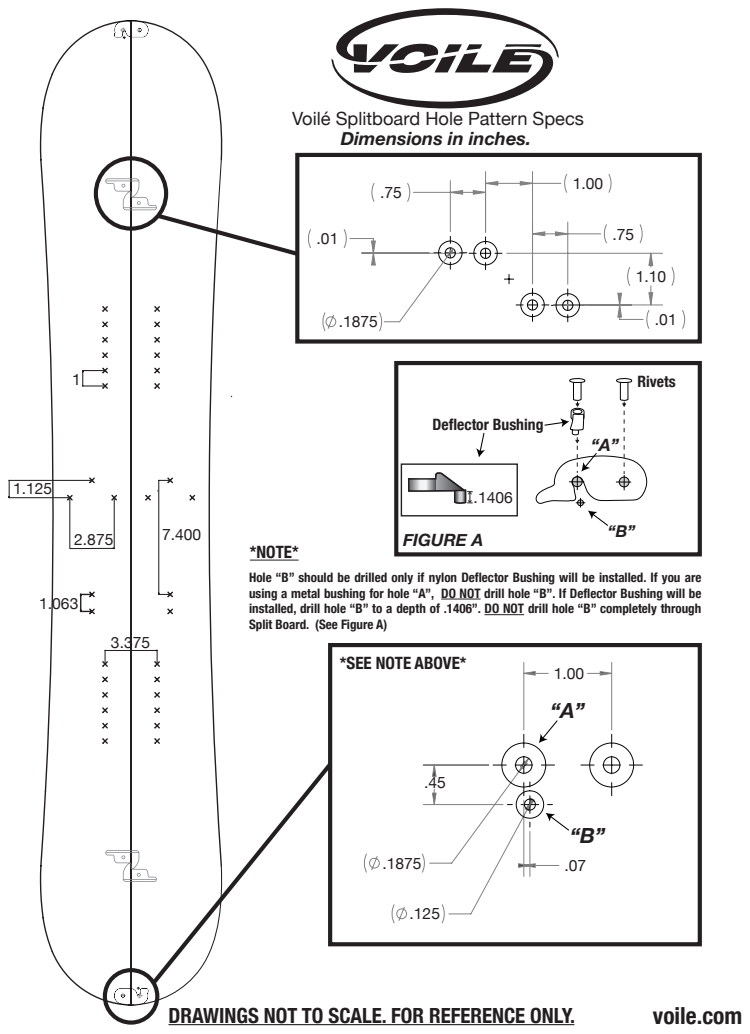
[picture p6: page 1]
Deflector Bushing; Rivets; FIGURE A; voile.com

*NOTE*
Hole “B” should be drilled only if nylon Deflector Bushing will be installed. If you are
using a metal bushing for hole “A”, DO NOT drill hole “B”. If Deflector Bushing will be
installed, drill hole “B” to a depth of .1406”. DO NOT drill hole “B” completely through
Split Board. (See Figure A)

*SEE NOTE ABOVE*

DRAWINGS NOT TO SCALE. FOR REFERENCE ONLY.

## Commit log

2023-05-03 Initial site conversion
    [Camber_Block_Original_Public_v8.f3d, Camber_Block_Original_Public_v8.step, End_Block_Original_1_Public_v4.f3d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]
2023-05-04 Fixed image links, table formatting, quotes, citations, moved non-image files out of assets/images and into static/files and fixed all links to them.
    [Camber_Block_Original_Public_v8.f3d, Camber_Block_Original_Public_v8.step, End_Block_Original_1_Public_v4.f3d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]
